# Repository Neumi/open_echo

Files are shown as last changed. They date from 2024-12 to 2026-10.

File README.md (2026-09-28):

<div align="center">
  Open Echo Cover
</div>

## Universal Open-Source SONAR Controller and Development Stack

An ongoing open-source hardware and software project for building sonar systems for testing, boating, bathymetry, and research.

[Discord](https://discord.com/invite/rerCyqAcrw) | [Getting Started Guide](TUSS4470_shield_002/README.md) | [Hardware Files](TUSS4470_shield_002/TUSS4470_shield_hardware/TUSS4470_shield)

## Overview

Open Echo makes SONAR technology accessible for developers, researchers, and hobbyists. It supports a wide variety of commercial and DIY ultrasonic transducers in both water and air, covering frequencies from 40 kHz up to 1000 kHz.

Use cases range from reverse-engineering car parking sensors and reading depth data on a yacht, to operating a Lowrance Tripleshot side-scan transducer or streaming data to a Pixhawk on a custom boat.

### Key Features

* **Universal Transducer Support:** Works with commercial and DIY transducers in water and air.
* **Flexible Firmware:** Run the [RAW Data Firmware](TUSS4470_shield_002/getting_started_TUSS4470_firmware.md) to process echoes yourself, or the [NMEA Output Firmware](TUSS4470_shield_002/arduino/NMEA_DBT_OUT/NMEA_DBT_OUT.ino) for NMEA0183 DBT compatibility (sends depth data directly to PCs, Pixhawk, or marine controllers).
* **Python Interface:** The [desktop software](TUSS4470_shield_002/getting_started_interface.md) provides live raw data visualization and TCP data streaming.
* **Tested Range:** Confirmed depth tracking of >50 m in water.
* **Network Ready:** Includes a PicoW implementation (software only, the shield itself is Arduino UNO R3 compatible) that transfers RAW data over UDP directly to the Python interface.

## Hardware & Getting Started

The primary development platform is the [TUSS4470 Arduino Shield](TUSS4470_shield_002/). It stacks directly on top of an Arduino Uno to drive the TUSS4470 ultrasonic driver.

**Upcoming Board:** A new development version is in the works and will hopefully be released in the coming weeks. It features an on-board boost converter and slightly improved signal routing.

* **Powering (Current Board):** Provide driver voltage via Arduino VIN or the external XT30 connector. You can also currently use an MT3608 boost converter to step up USB power to your required drive voltage (requires manual soldering until the new board is released).
* **Capabilities:** Drives transducers from 40–1000 kHz, filters signals, and sends raw echo data to the backend. It captures 1800 samples at 13.2 µs/sample (roughly an 18m range in water at 8-bit resolution). You can manually add delays in the code to extend the detection range for further distances.

### Getting the Hardware

1. **Elecrow (Pre-Built):** Buy a fully assembled and tested board here: [Elecrow Open Echo TUSS4470](https://www.elecrow.com/open-echo-tuss4470-development-shield.html)
2. **Build Your Own:** Order the [Hardware Files](TUSS4470_shield_002/TUSS4470_shield_hardware/TUSS4470_shield) from your preferred PCB manufacturer (JLCPCB recommended).
3. **Directly from me (Germany/EU):** If Elecrow is out of stock or you want to reduce shipping costs within Germany, email me at: `openechoes@gmail.com`.

> **Note:** All profits go directly toward supporting the project. Please understand that I can only provide support if you order the boards directly from me or Elecrow.

## Open Echo Interface Software

The [Python Interface Software](TUSS4470_shield_002/echo_interface.py) connects to boards running the RAW Data Firmware. It serves as a simple backend to view live echograms and output TCP depth data streams. (Configuration tweaking directly from the UI will be added later).

Live echogram in water (6x speed):  
Software running with live echo data

*(Static raw data waterfall chart available [here](documentation/images/echo_software_screenshot.jpg))*

## Test Results: Baltic Sea

Tested using a built-in 150 kHz SEAFARER transducer, powered at 15-20 V via an MT3608 boost converter from USB. Data capture in the plots begins at the bottom.

<table>
  <tr>
    <td align="center">
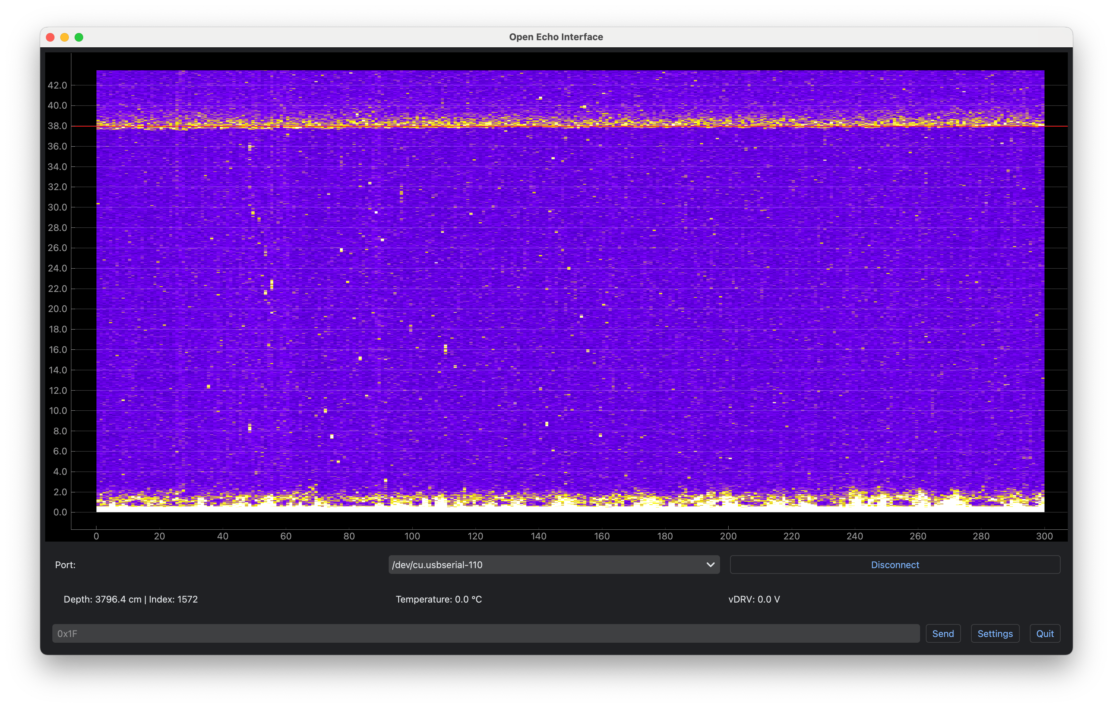
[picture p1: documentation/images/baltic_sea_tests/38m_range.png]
38m Range
      <br/>
      <sub><b>38 m range test</b></sub>
    </td>
    <td align="center">
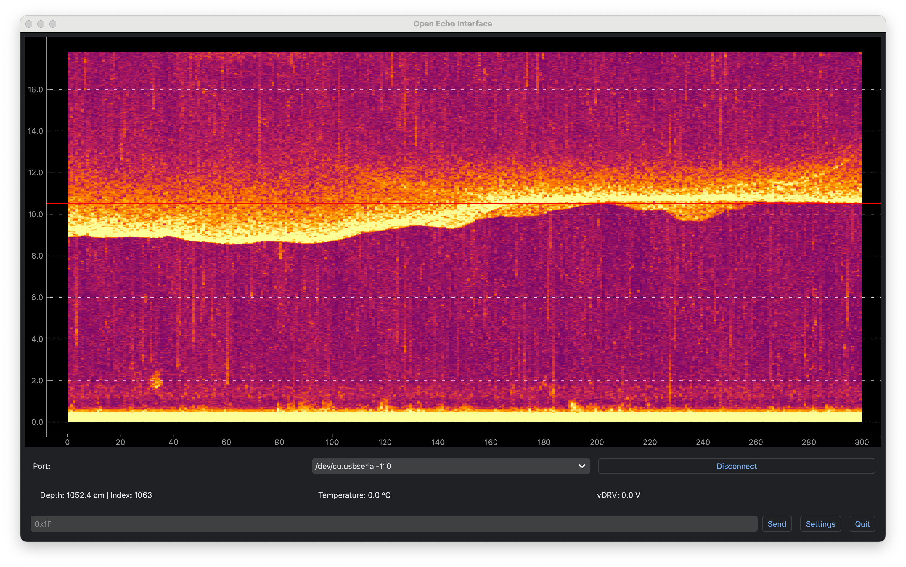
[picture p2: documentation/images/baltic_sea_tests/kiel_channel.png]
Kiel Channel
      <br/>
      <sub><b>Kiel Channel sand and mud</b></sub>
    </td>
    <td align="center">
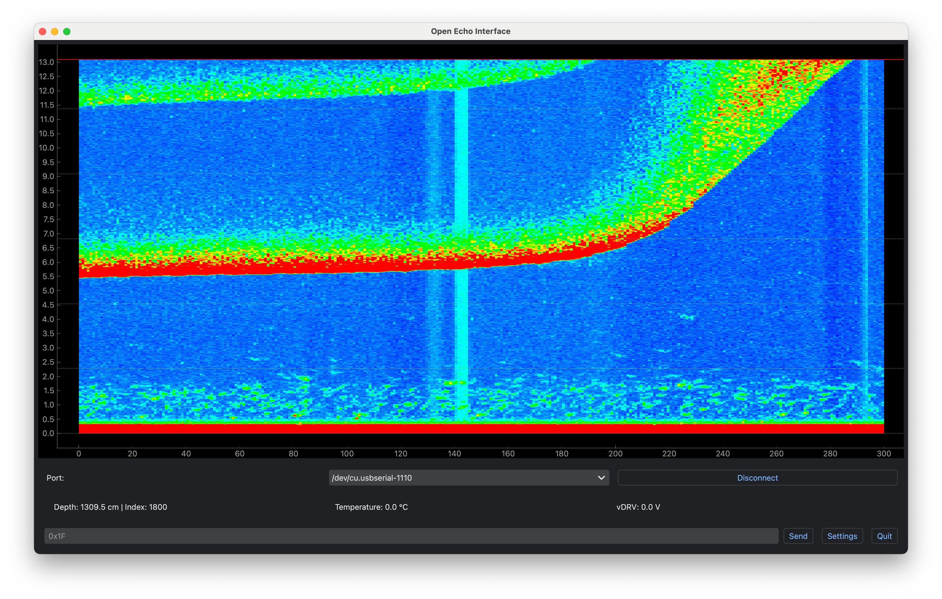
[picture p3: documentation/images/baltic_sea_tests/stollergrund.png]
Stollergrund
      <br/>
      <sub><b>Slope near Stollergrund</b></sub>
    </td>
  </tr>
  <tr>
    <td align="center">
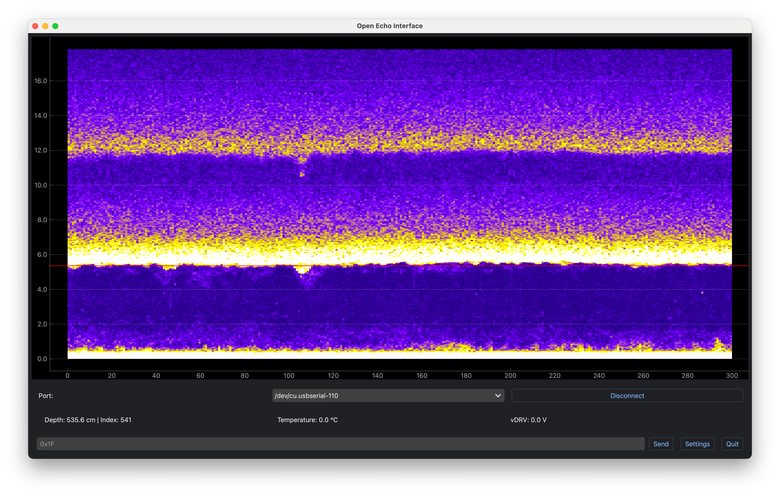
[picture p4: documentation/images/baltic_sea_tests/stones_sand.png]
Stones and Sand
      <br/>
      <sub><b>Stones and sandy seabed</b></sub>
    </td>
    <td align="center">
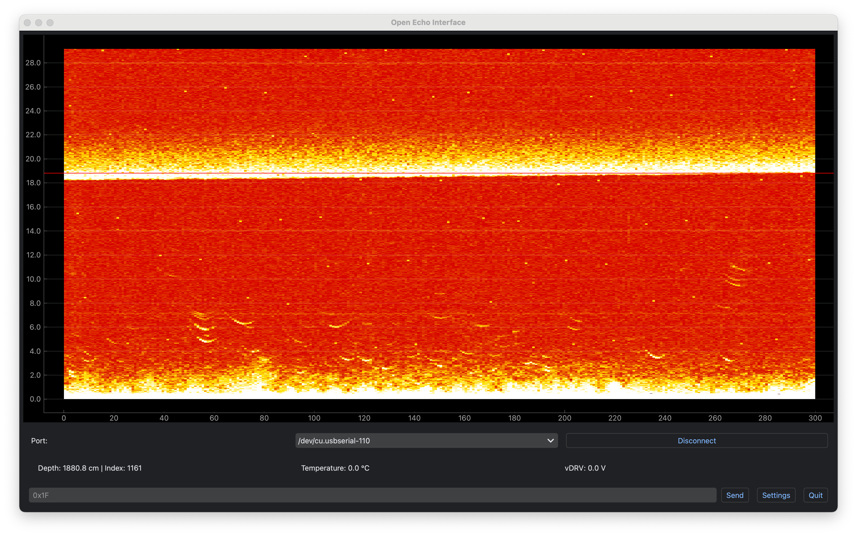
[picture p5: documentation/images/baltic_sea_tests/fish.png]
Fish
      <br/>
      <sub><b>Fish detection</b></sub>
    </td>
    <td align="center">
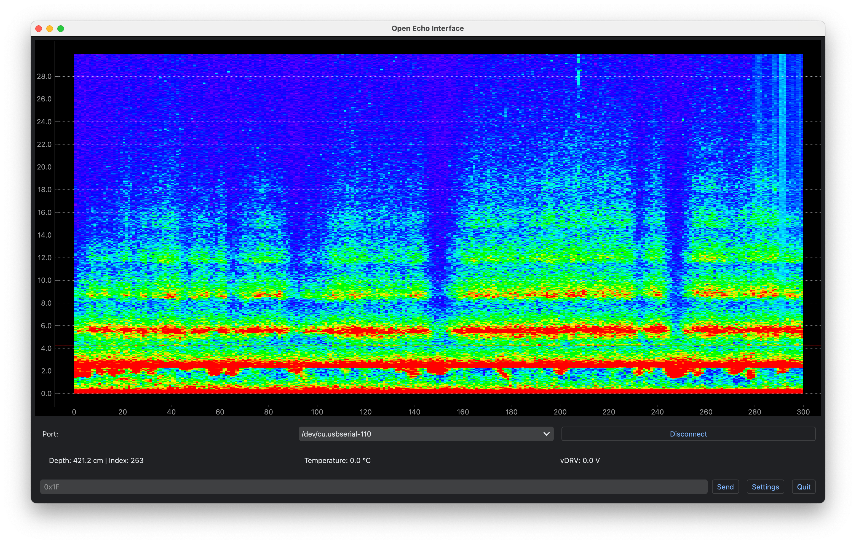
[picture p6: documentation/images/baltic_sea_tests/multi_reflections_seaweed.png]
Multiple Reflections
      <br/>
      <sub><b>Multiple reflections and seaweed</b></sub>
    </td>
  </tr>
</table>

## Transducers

Open Echo has been tested with multiple transducers. Here is a curated list of tested hardware:

| Transducer Name | Rating | Description | Freq. | Range Air/Water | Price | Link |
| --- | --- | --- | --- | --- | --- | --- |
| NASA / Seafarer 150kHz | ⭐⭐⭐ | NASA in-hull boat transducer for echo sounding / fish-finding | 150kHz | >2m / >50m | 50-100€ | [Link](https://www.nasamarine.com/product/depth-transducer-with-7-metre-cable/7) |
| Raymarine CPT-S | ⭐⭐⭐ | High-quality in-hull transducer with two frequencies | 50/200kHz | 2m / >50m | 200€ | [Link](https://www.raymarine.com/de-de/unsere-produkte/fischfinder-und-sonarmodule/fischfindergeber/cpt-s-durchbruchgeber) |
| Lowrance Tripleshot | ⭐⭐⭐ | Sidescan transducer (three FANS + temp + down-scan) | 200/455/600kHz | 0m / >20m | 200€ | [Link](https://www.echolotzentrum.de/shop/lowrance-tripleshot-heckgeber/) |
| Cheap Bathymetry | ⭐⭐⭐ | Good range and price/performance (can be hard to order) | 200kHz | 2m / >30m | 25€ | [Link](https://www.alibaba.com/product-detail/Range-customization-lakes-river-surveys-no_1600829423846.html) |
| Car Parking Sensor | ⭐⭐ | Great for air, works in water (not recommended for marine) | 40kHz | >7m / >30m | 5€ | [Link](https://de.aliexpress.com/item/1005006546490802.html) |
| Water Flow Sensor | ⭐⭐ | Cheap (Air & Water). Very narrow beam in water (~5°)! | 1000kHz | 0.25m / >10m | 16€ (5pcs) | [Link](https://de.aliexpress.com/item/32818381566.html) |
| Sinter Glass (Air Only) | ⭐ | Sinter glass matching layer, strictly for air use | 200kHz | 0.8m / (>8m) | 10€ | [Link](https://de.aliexpress.com/item/1005006007865920.html) |
| Encapsulated Transducers | ⭐ | Good for short-range testing at higher frequencies | 200-400kHz | ?m / ?m | 9-18€ | [Link](https://de.aliexpress.com/item/4000389134890.html) |
| Small PZT Only | ⭐ | Bare component, only for raw experimentation | 200kHz | 0.2m / ?m | 10€ | [Link](https://de.aliexpress.com/item/1005007032482539.html) |

> **Note:** The range values were measured using the TUSS4470 shield on an Arduino Uno with an MT3608 boost converter set to 20V for `vDRV`. Consider them approximate.

> **Tip:** Lower frequencies propagate farther, while higher frequencies produce narrower beams and more detailed echoes. For bathymetry, the first four options work best. Most commercial marine-grade transducers are suitable as long as they operate between 40 and 1000 kHz.

## Media & Resources

### Videos

Latest Project Update (https://www.youtube.com/watch?v=XF7rNGt6UYA)

https://www.youtube.com/watch?v=R3_NO2F7PsI  
https://www.youtube.com/watch?v=msbLVsY8xhQ  
https://www.youtube.com/watch?v=eJ8jVEQSx_Y  
https://www.youtube.com/watch?v=Bxh3rWd5RZk  
https://www.youtube.com/watch?v=UDYWQIizN7A  

### Links

* [Rapp Instruments: Side-Scan Sonar Info](https://www.rapp-instruments.de/RemoteSensing/Roves/sidescan/sidescan.htm)
* [Related Sonar Explanation Video](https://www.youtube.com/watch?v=ZtUkt8Q4EJE)

## Acknowledgments & Support

A big thanks to **[www.kogger.tech](http://www.kogger.tech)** for their continued support!

Thanks to our contributors:
* Check out the [Cheap Yellow Display Implementation](https://github.com/matztam/open_echo_cyd_display) by @matztam.
* Thanks to [@JohnCHarrington](https://github.com/JohnCHarrington/open_echo) for the firmware and software contributions.

### Star History
Star History Chart (https://www.star-history.com/#Neumi/open_echo&type=date&legend=top-left)

## Citation

If you use `open_echo` in your work or research, please cite the project:

* **ORCID:**  [0009-0003-9829-8959](https://orcid.org/0009-0003-9829-8959)

**BibTeX:**

```bibtex
@misc{open_echo,
  author       = {Jan Neumann},
  title        = {open\_echo},
  year         = {2026},
  publisher    = {GitHub},
  journal      = {GitHub Repository},
  howpublished = {\url{[https://github.com/Neumi/open_echo](https://github.com/Neumi/open_echo)}},
  note         = {ORCID: [https://orcid.org/0009-0003-9829-8959](https://orcid.org/0009-0003-9829-8959)}
}

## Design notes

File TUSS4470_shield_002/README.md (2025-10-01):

# Open Echo TUSS4470 Shield Getting Started Guide

The TUSS4470 is an ultrasonic driver and receiver IC designed for seamless interaction with ultrasonic transducers. The TUSS4470 Arduino Shield is a development board that enables quick evaluation of the TUSS4470's features using the Arduino UNO platform.

### Overview
This repository provides a quick-start guide and example Arduino sketches for experimenting with Time-of-Flight (ToF) applications using the TUSS4470. The shield is ideal for development, testing, and prototyping, but is not intended as a finished consumer product.

### Getting Started
Connect the shield to an Arduino UNO.

Upload one of the provided example sketches to explore different features of the TUSS4470.

Use the Python software to see the echoes.

### Ordering
The shield can be easily ordered via [JLCPCB](https://jlcpcb.com/?from=Neumi) or other PCB fabrication services.

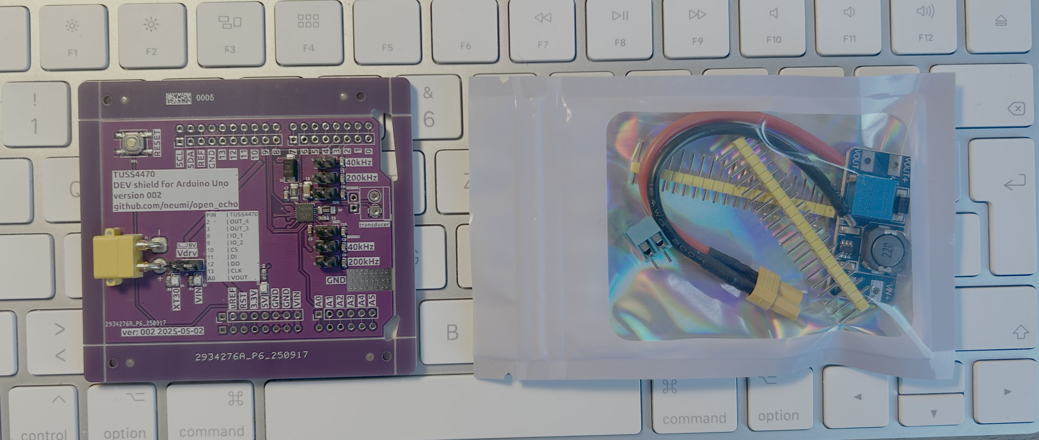
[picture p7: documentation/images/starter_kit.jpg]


> [!Note]
> I just got a few new boards, I sell as starter kits. Feel free to DM me on [Discord](https://discord.com/invite/rerCyqAcrw) if you're interested. Or send an email to: openechoes@gmail.com One assmebled board is 50€ + shipping. (10/2025)

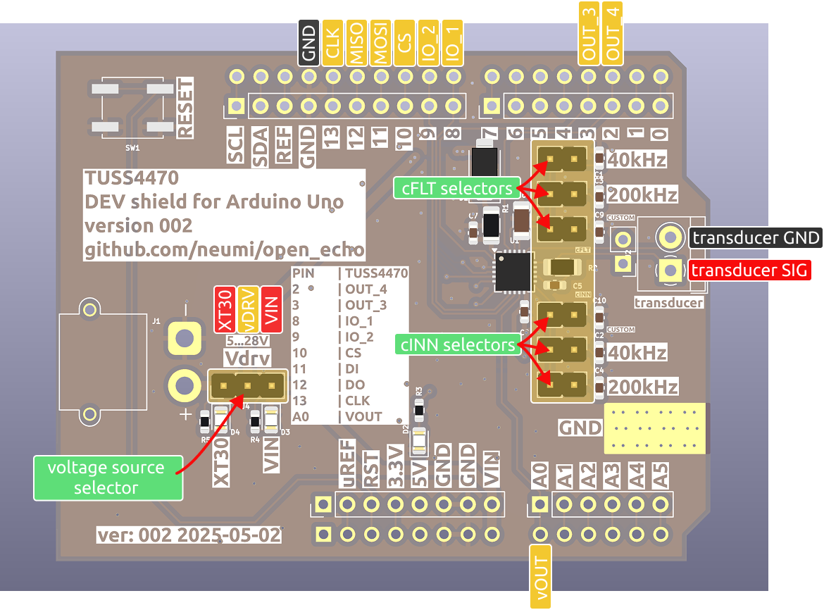
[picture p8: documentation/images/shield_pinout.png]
PCB overview TUSS4470


## Electrical Connections
The TUSS4470 Shield is designed specifically for use with the Arduino UNO. It is not software- or pin-compatible with other Arduino boards at this time.

### Pin Connections
The shield interfaces with the Arduino UNO the following:
- SPI interface
- Four digital GPIOs
- Analog pin A0

### cINN and cFLT Filtering Capacitor Selection for Transducer Frequency
To support different ultrasonic transducers and their respective drive frequencies, the board provides preset capacitor options for <b/>40, 150, 200 (and 600) kHz</b>.

> [!Important]
> Use the onboard jumpers to select the appropriate cINN and cFLT values.

### Custom Capacitor Configuration
If you need to drive transducers at frequencies other than the provided presets and combinations (40 kHz, 150 kHz, 200 (and 600) kHz), you can customize the capacitor values:
- Desolder the default "CUSTOM" capacitors. (for cINN and cFLT)
- Solder your own calculated capacitor values onto the "CUSTOM" pads.

> [!TIP]
> Capacitors can be combined in parallel to achieve intermediate values.
> For example, to support 150 kHz, both the 200 kHz and CUSTOM capacitors are used in parallel to produce the required total capacitance.
> On board version 002, "Custom" is pre-selected to match the right capacitances <b/>together</b> with the 200kHz capacitors for 150kHz. 

Below is the electrical connection layout for the cINN and cFLT capacitors and jumpers:
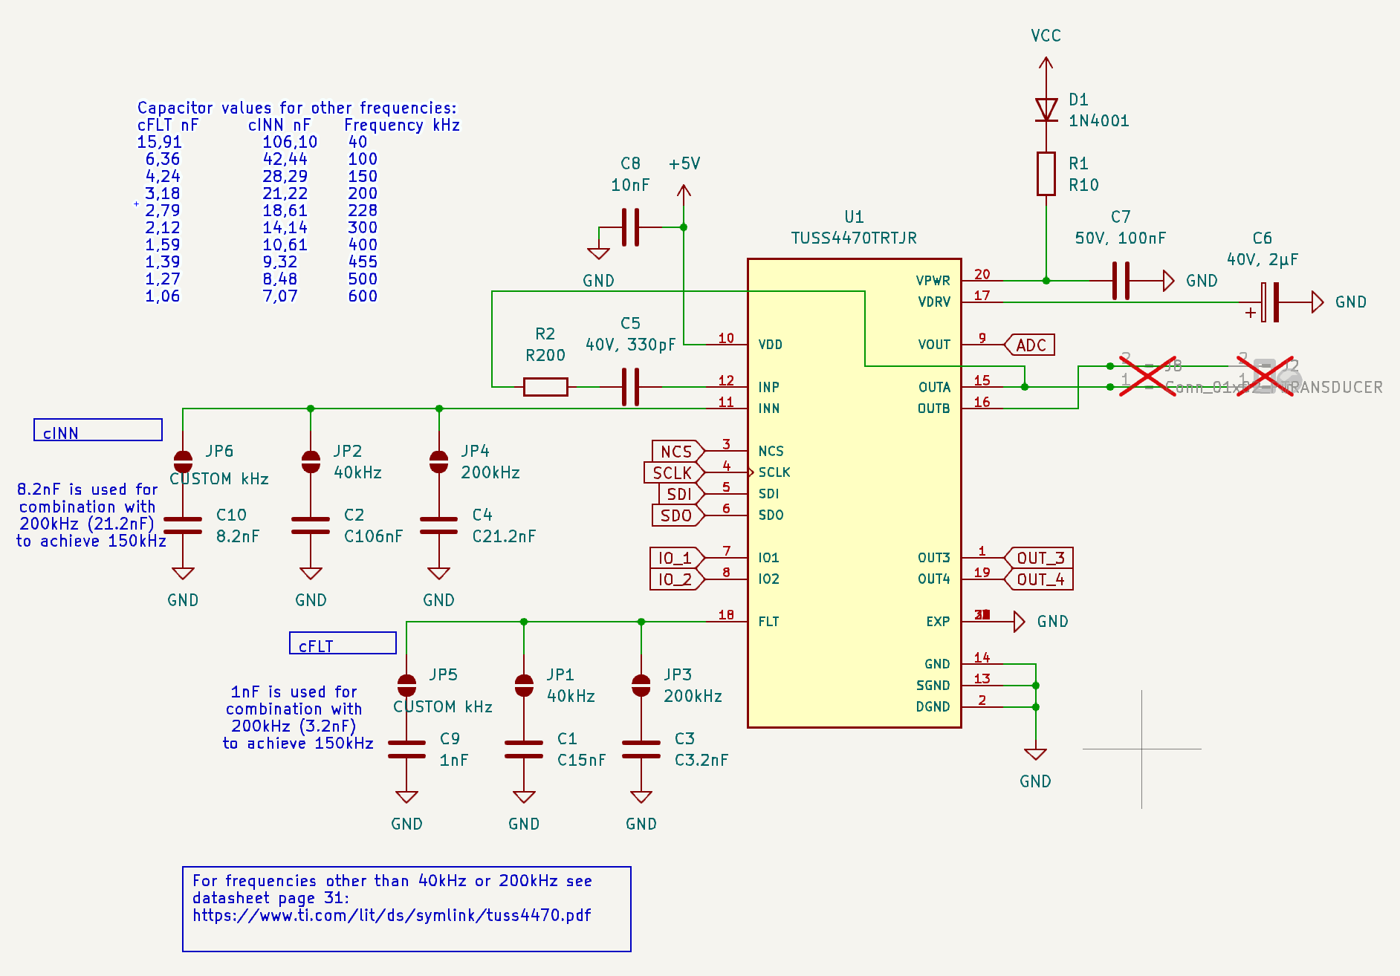
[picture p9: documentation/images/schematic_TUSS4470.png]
TUSS4470 schematic


### Power Supply Options
The board supports two power input options:
- VIN (Arduino VIN pin):
Use this when the transducer operates at 12V max, as the Arduino cannot tolerate higher voltages.

- XT30 Connector:
Use this if you require higher voltage (up to 28V max) for more powerful transducers.

- MT3608 Boost Converter:
You can add an MT3608 boost converter to your board to generate a higher vDRV from the USB 5V supply. This solution is reliable and works well in many applications, such as powering marine transducers.
Simply take the MT3608 module (included in the starter kits), secure it to the shield with double-sided tape, and connect the three wires as shown:
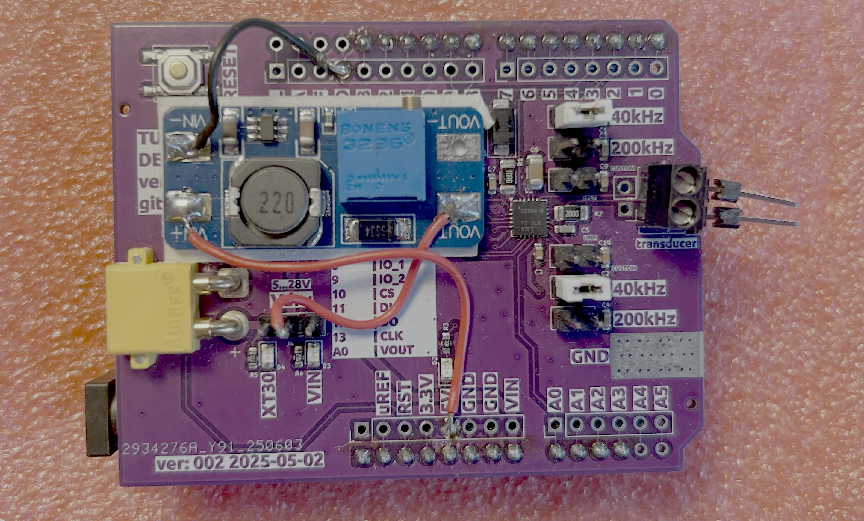
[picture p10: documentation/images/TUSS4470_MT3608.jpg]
TUSS4470 schematic


> [!Tip]
> To get started, use a 12V power supply. Many ultrasonic transducers operate reliably at this voltage.
> 
> Lower voltages may not adequately excite the transducer, resulting in weak or no echo signals.
> 
> The MT3608 should not be turned much further than 22V, as it becomes unstable.

> [!Warning]
> Do not exceed 28V input. Higher voltages can damage the board or components. Ensure proper polarity!

### Transducer Connection
Connect your PZT crystal or preassembled ultrasonic transducer to the "Transducer" header:

- Top pin: Ground (GND) / Shield
- Bottom pin: Signal

> [!Important]
> Proper polarity is crucial to minimize electrical noise and ensure optimal performance.
> For transducer connections exceeding 10 cm in length, use coaxial cable. Connect the cable shield to the transducer ground (GND).

The recommended setup is illustrated below:
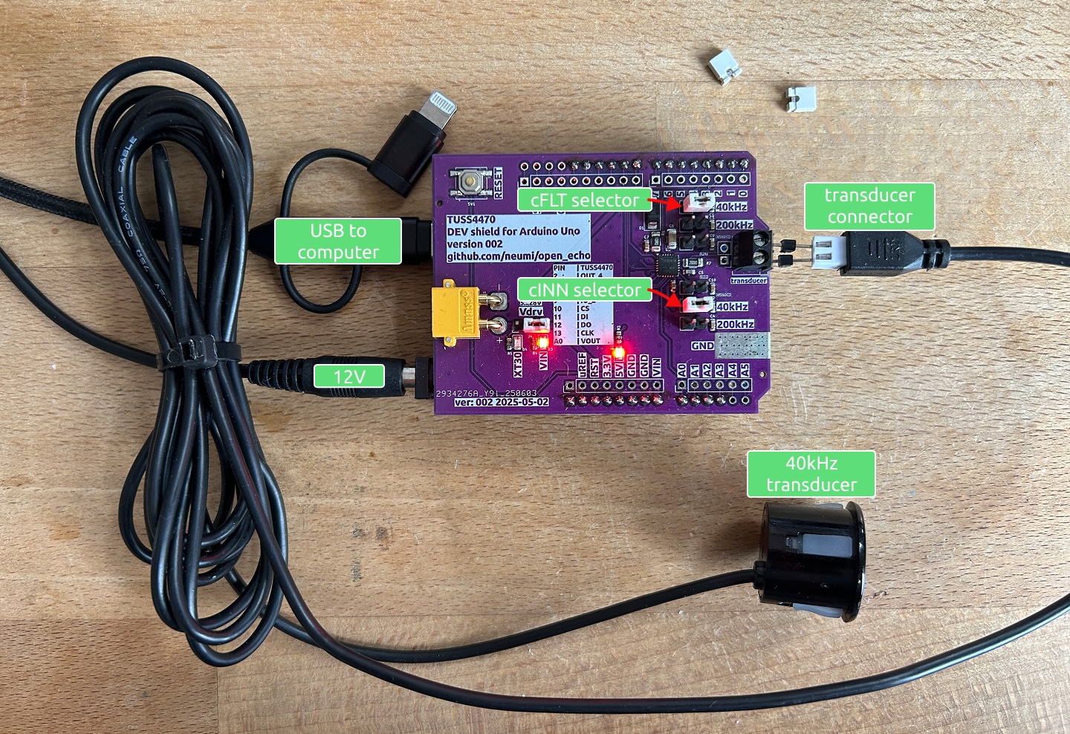
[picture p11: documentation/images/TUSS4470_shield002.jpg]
TUSS4470 Board ready to use


> [!Important]
> Always connect GND/Shield to the TOP pin on the transducer.
> Using the wrong pin increases powerline noise and significantly weakens the signal.

Below: Comparison of a transducer wired incorrectly (left half) vs. correctly (right half).
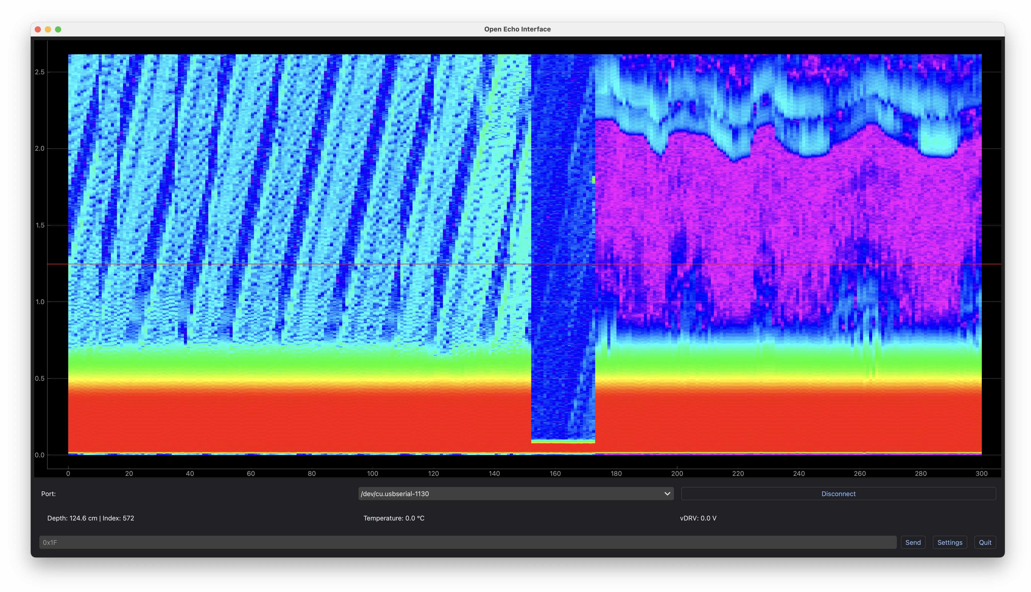
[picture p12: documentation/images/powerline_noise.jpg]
Powerline noise on transducer cable shield


<b/>Next Steps: Proceed to [Getting Started with Arduino TUSS4470 Firmware](getting_started_TUSS4470_firmware.md).</b>

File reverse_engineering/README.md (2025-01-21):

# open_echo

Reverse engineering of the LUCKY fishfinder to learn about ultrasonics projects from a real product.

Using a trigger and analog pin on an Arduino UNO we can read RAW echo data from the LUCKY fishfinder product.

As of today, there are at least three hardware versions of the LUCKY fishfinder. All of them seem to follow a similar concept, but the pinout is different!

LUCKY fishfinder pins:
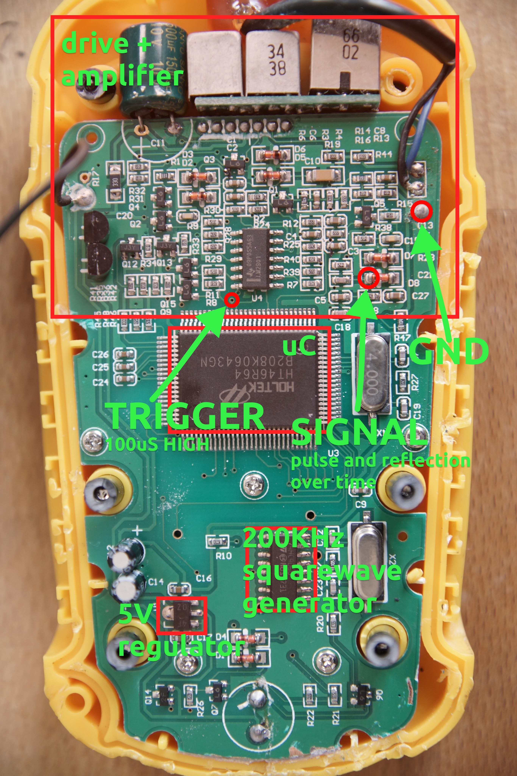
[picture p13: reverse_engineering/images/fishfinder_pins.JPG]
LUCKY fishfinder pin hack


Measured results using LUCKY fishfinder, FastLOGIC (Arduino) and Matplotlib + Python:
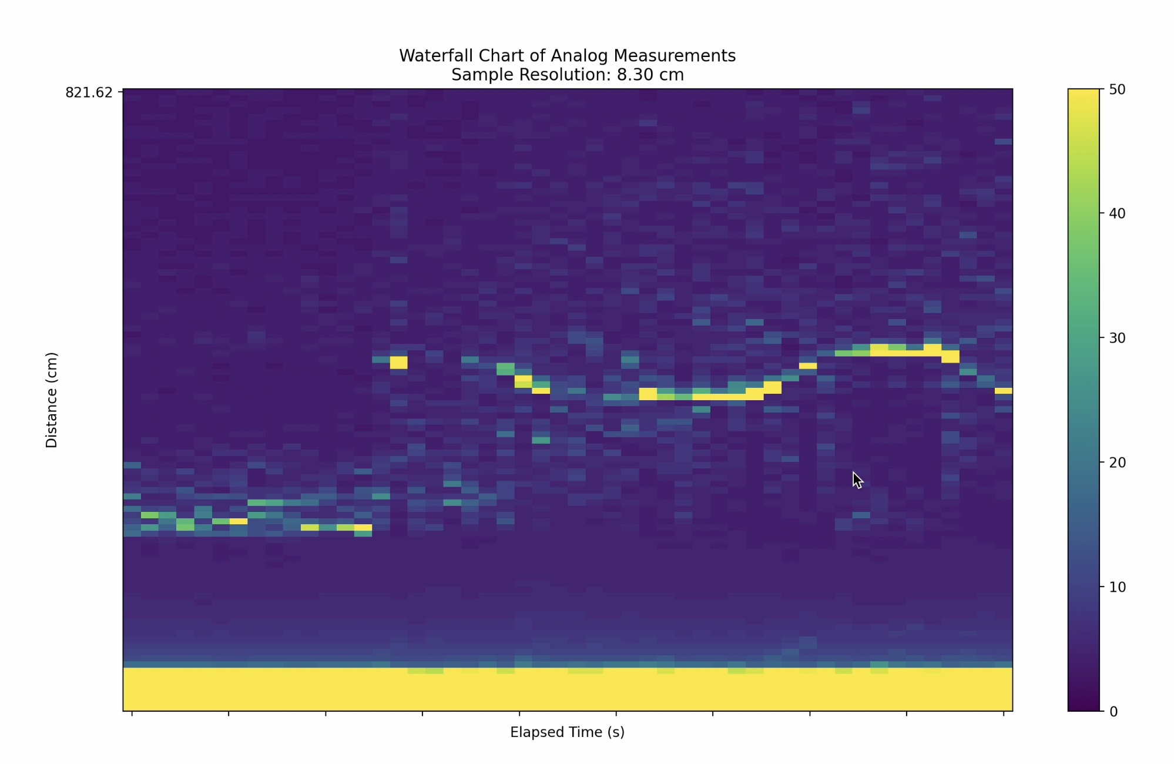
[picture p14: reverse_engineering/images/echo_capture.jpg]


The chart shows a measurement of reflection time (translated to cm using 1482m/s speed of sound in water) and the past 50 measurements. The LUCKY fish finder takes around 2.3 full measurements per second. The brigter the pixel, the stronger the return signal. The plot shows the sandy ground in the first 1/4 and the rest is the reflection of a metal ladder in the water (horizontal).

# More info in this video:
LINK TO VIDEO (https://www.youtube.com/watch?v=UDYWQIizN7A)

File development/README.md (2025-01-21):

# open_echo development
Less tested code, PCB designs and files. Not documented or ready for external use.

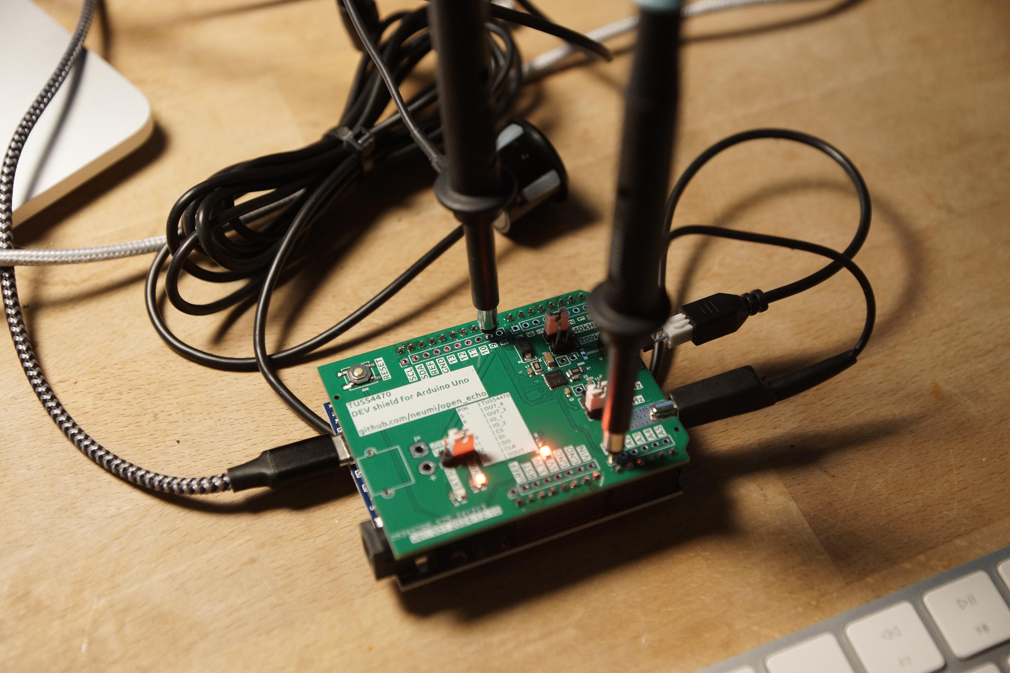
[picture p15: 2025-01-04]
TUSS4470_shield_002/TUSS4470_shield_hardware/images/perspective.jpg

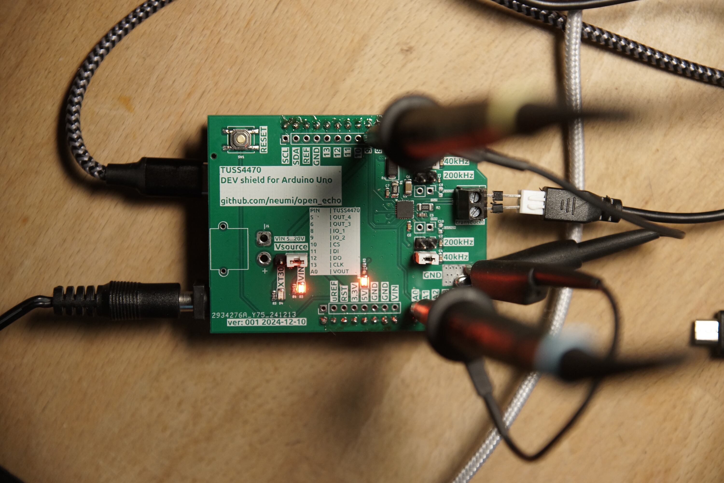
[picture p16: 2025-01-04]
TUSS4470_shield_002/TUSS4470_shield_hardware/images/top.jpg

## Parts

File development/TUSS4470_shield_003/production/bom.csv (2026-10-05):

Designator | Footprint | Quantity | Value | LCSC Part #
C1 | 0603 | 1 | 47pF 50V | C1671
C11 | 0603 | 1 | 1nF | C1588
C12 | 0603 | 1 | C15nF | C1596
C13 | 0603 | 1 | C3.2nF | C1613
C14 | 0603 | 1 | 8.2nF | C1322360
C15 | 0603 | 1 | C106nF | C14663
C16 | 0603 | 1 | C21.2nF | C21122
C17 | 0603 | 1 | 680pF | C1630
C18 | 0603 | 1 | 4.7nF | C53987
C2 | 1206 | 1 | 10uF 50V X5R | C13585
C3, C4 | 1206 | 2 | 4.7uF 50V X7R | C29823
C5 | 0603 | 1 | 40V, 330pF | C1664
C6 | 1206 | 1 | 40V, 2µF | C50254
C7, C9 | 0603 | 2 | 50V, 100nF | C14663
C8 | 0603 | 1 | 10nF | C57112
D1 | D_SMA | 1 | SMAJ36A | C19077550
D2 | 0805 | 1 | LED_PWR | C84256
D3, D5 | Nexperia_CFP3_SOD-123W | 2 | PMEG6010ELR | C179432
D4 | 0805 | 1 | LED_VPWR | C84256
J2 | PinHeader_1x03_P2.54mm_Vertical | 1 | TRANSDUCER
J4 | PinHeader_1x03_P2.54mm_Vertical | 1 | vINN SELECT | C49257
J9 | TerminalBlock_4Ucon_1x03_P3.50mm_Horizontal | 1 | TRANSDUCER
L1 | L_Taiyo-Yuden_NR-60xx | 1 | L | C16218
R1 | 1206 | 1 | R10 | C17903
R2 | 1206 | 1 | R200 | C25361
R3 | 0603 | 1 | R330 | C23138
R4 | 0603 | 1 | 374k | C25815
R5 | 0603 | 1 | R2.2k | C4190
R6 | 0805 | 1 | 0OHM | C17477
R7 | 0603 | 1 | 13.7k | C325658
R8 | 0603 | 1 | 75k | C23242
R9 | 0603 | 1 | 10k | C25804
SW1 | SW_Push_1P1T_NO_CK_KSC7xxJ | 1 | RST | C318884
U1 | QFN-20-1EP_4x4mm_P0.5mm_EP2.5x2.5mm_ThermalVias | 1 | TUSS4470TRTJR | C1855776
U2 | SOT-23-5 | 1 | LM2733XMF

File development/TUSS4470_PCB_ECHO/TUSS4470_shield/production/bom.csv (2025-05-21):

Designator | Footprint | Quantity | Value | LCSC Part #
C1, C21, C23, C8 | 0603 | 4 | 50V, 100nF | C14663
C10, C2 | 1206 | 2 | C10uF | C13585
C11, C13, C18, C28 | 0603 | 4 | C100nF | C14663
C12, C14 | 0603 | 2 | C10nF | C57112
C15, C16 | 0402 | 2 | C1nF | C1523
C17 | 0402 | 1 | C2.2nF | C1531
C19 | 0603 | 1 | 10nF | C57112
C20 | 0603 | 1 | 40V, 330pF | C1664
C22 | 0603 | 1 | C47nF | C1622
C24 | 0805 | 1 | C10uF | C440198
C25 | 1206 | 1 | 40V, 2µF | C50254
C29 | 1206 | 1 | C22uF | C12891
C3, C6, C7, C9 | 0402 | 4 | C100nF | C307331
C30 | 1210 | 1 | C22uF | C778721
C4, C5 | 0402 | 2 | C22pF | C1555
D1 | 0805 | 1 | LED_PC13 | C84256
D10, D5 | D_SMA | 2 | D_Schottky | C8678
D2, D3, D9 | D_SOD-323 | 3 | D_Schottky | C2128
D4 | 0805 | 1 | TX | C2297
D7 | 0805 | 1 | RX | C2297
INP1 | PinHeader_1x01_P2.54mm_Vertical | 1 | INP
J1 | TO-92L_Inline | 1 | DS18B20 | C157928
J2 | 200kHz_piezo | 1 | TRANSDUCER | C2997509
JP1 | PinHeader_1x02_P2.54mm_Vertical | 1 | termination_jumper
JP2 | SolderJumper-2_P1.3mm_Open_RoundedPad1.0x1.5mm | 1 | TVS
JP4 | SolderJumper-2_P1.3mm_Open_RoundedPad1.0x1.5mm | 1 | TRANSFORMER_BRIDGE
JP6 | SolderJumper-2_P1.3mm_Open_RoundedPad1.0x1.5mm | 1 | PHASE_DETECT
JP7 | SolderJumper-2_P1.3mm_Open_RoundedPad1.0x1.5mm | 1 | TRANSDUCER_GND
L1 | L_Bourns_SRN6045TA | 1 | L22uH | C780213
OUTA1 | PinHeader_1x01_P2.54mm_Vertical | 1 | OUTA
OUTB1 | PinHeader_1x01_P2.54mm_Vertical | 1 | OUTB
PIEZOA1 | PinHeader_1x01_P2.54mm_Vertical | 1 | TRANSDUCER_A
PIEZOB1 | PinHeader_1x01_P2.54mm_Vertical | 1 | TRANSDUCER_B
R1 | 0402 | 1 | R1M | C26083
R10, R14, R2 | 0603 | 3 | R1k | C21190
R11 | 1206 | 1 | R10 | C17903
R12 | 0603 | 1 | R4.7k | C23162
R13 | 1206 | 1 | R200 | C18002
R15 | 0402 | 1 | R100k | C25741
R16 | 0603 | 1 | R2.2k | C4190
R3, R4, R5, R6, R9 | 0603 | 5 | R10k | C25804
R7, R8 | 0603 | 2 | R330 | C23138
RV1 | Potentiometer_Bourns_3296W_Vertical | 1 | R_POT_100k
SW1 | SW_Push_1P1T_NO_CK_KSC7xxJ | 1 | RST | C318884
T1 | ultrasonic_transformer_THT | 1 | Transformer_1P_SS
TP1, TP3, TP5 | TestPoint_Pad_D2.0mm | 3 | GND
TP2 | PinHeader_1x01_P2.54mm_Vertical | 1 | BOOST
TP6 | TestPoint_Pad_D2.0mm | 1 | D-
TP7 | TestPoint_Pad_D2.0mm | 1 | D+
TP8 | TestPoint_Pad_D2.0mm | 1 | 5V
TP9 | PinHeader_1x01_P2.54mm_Vertical | 1 | VPWR
U1 | SOT-223-3_TabPin2 | 1 | AMS1117-3.3 | C6186
U2 | LQFP-48_7x7mm_P0.5mm | 1 | STM32F103C8Tx | C8734
U3 | QFN-28-1EP_5x5mm_P0.5mm_EP3.35x3.35mm | 1 | CP2102N-A01-GQFN28 | C6568
U4 | QFN-20-1EP_4x4mm_P0.5mm_EP2.5x2.5mm_ThermalVias | 1 | TUSS4470TRTJR | C1855776
U5 | SOT-23-6 | 1 | MT3608 | C84817
Y1 | Crystal_SMD_5032-2Pin_5.0x3.2mm | 1 | Crystal | C115962

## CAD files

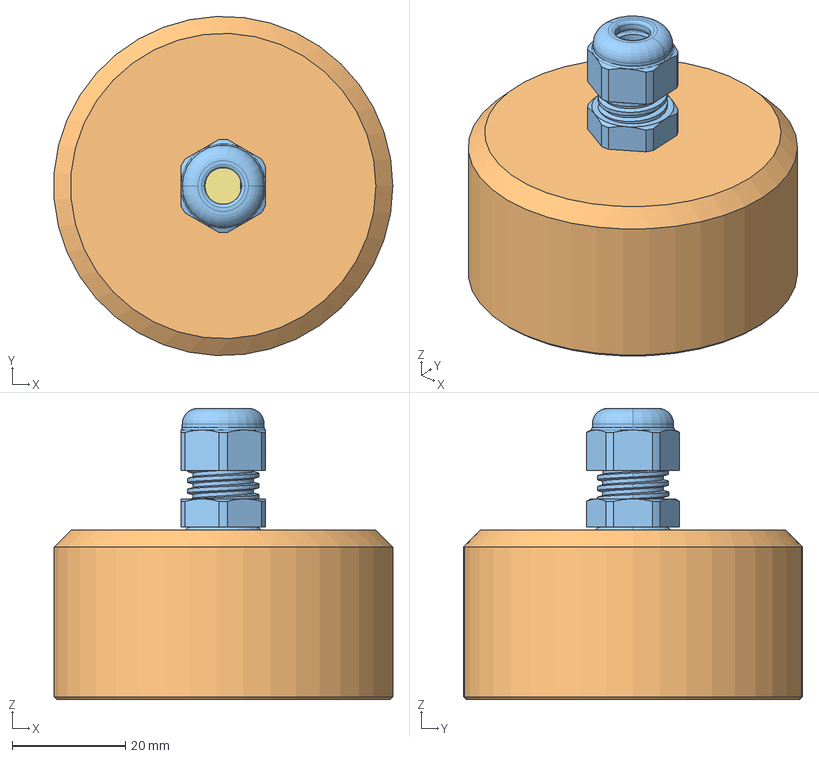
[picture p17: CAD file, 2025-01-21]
development/TUSS4470_PCB_ECHO/assembly.FCStd
59.9 x 60.0 x 51.5 mm
C_1206_3216Metric
R_1206_3216Metric
C_0402_1005Metric
R_0603_1608Metric
LED_0805_2012Metric
R_0603_1608Metric002
R_0402_1005Metric
C_0402_1005Metric002
QFN-20-1EP_4x4mm_Pitch0.5mm
D_SMA
R_0603_1608Metric004
C_0603_1608Metric
R_0603_1608Metric006
C_0402_1005Metric004
C_1206_3216Metric002
LED_0805_2012Metric002
LED_0805_2012Metric004
LQFP_48_7x7mm_P05mm
C_0603_1608Metric002
C_0603_1608Metric004
C_0402_1005Metric006
C_1206_3216Metric004
R_0603_1608Metric008
LED_0805_2012Metric006
C_1206_3216Metric006
C_0603_1608Metric006
SOT_223
R_1206_3216Metric002
LED_0805_2012Metric008
Crystal_SMD_5032-2Pin_5.0x3.2mm
C_0402_1005Metric008
C_0402_1005Metric010
C_0603_1608Metric008
R_0603_1608Metric010
R_0603_1608Metric012
R_0603_1608Metric014
C_1206_3216Metric008
C_0603_1608Metric010
QFN-28-1EP_5x5mm_Pitch0.5mm
_autosave-TUSS4470_shield_PCB
69915K47_Plastic Submersible Cord Grip

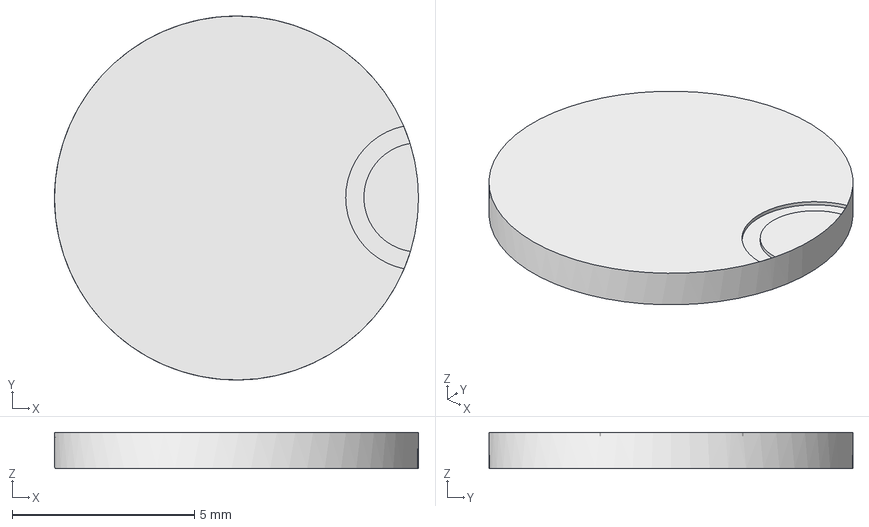
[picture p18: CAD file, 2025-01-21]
development/TUSS4470_PCB_ECHO/TUSS4470_shield/components/piezo_3d.step
10.00 x 10.00 x 1.00 mm

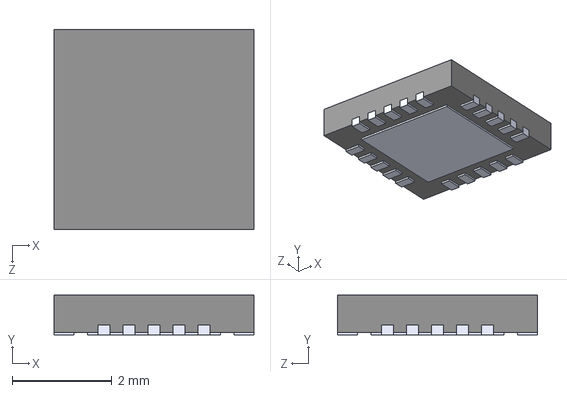
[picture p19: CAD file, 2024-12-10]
development/TUSS4470_shield_003/components/TUSS4470TRTJR.step
4.00 x 0.8 x 4.00 mm

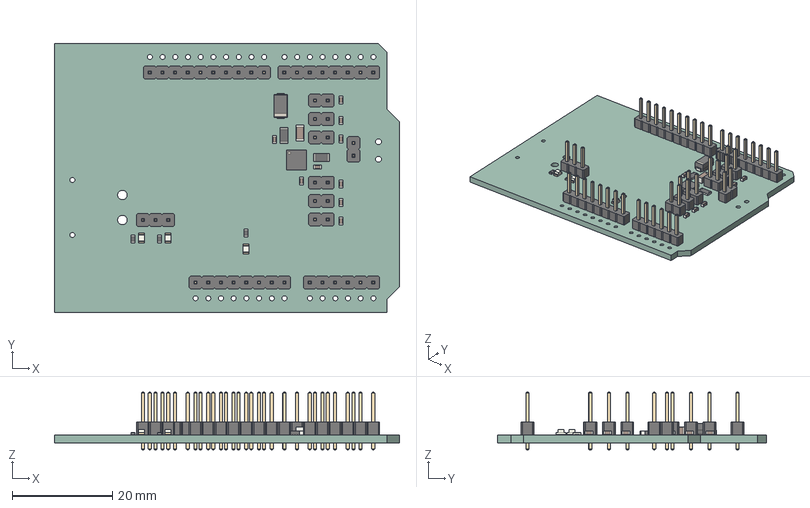
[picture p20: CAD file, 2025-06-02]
development/TUSS4470_shield_003/TUSS4470_shield.step
69.0 x 53.8 x 11.5 mm
R_1206_3216Metric x 2
LED_0805_2012Metric x 3
QFN-20-1EP_4x4mm_Pitch0.5mm
D_SMA
C_0603_1608Metric x 9
PinHeader_1x02_P254mm_Vertical x 7
PinHeader_1x06_P254mm_Vertical
R_0603_1608Metric x 3
C_1206_3216Metric
PinHeader_1x08_P254mm_Vertical x 2
PinHeader_1x10_P254mm_Vertical
PinHeader_1x03_P254mm_Vertical
TUSS4470_shield_PCB

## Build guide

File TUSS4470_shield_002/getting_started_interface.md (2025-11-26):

# Getting Started Open Echo Interface Software

The [***Open Echo Interface***](echo_interface.py) is a cross-platform Python application that interacts with the Arduino + TUSS4470 Shield. 
It displays ultrasonic echo data in real-time using a waterfall chart visualization. 
The application is intended primarily as a testing and development tool, but is stable enough for continuous use -tested for several days on a Raspberry Pi 4 without issues.

### Key Features
- Connects to Open Echo hardware over serial or UDP
- Displays real-time and historical data in a waterfall chart
- Auto-gain to adjust the waterfall chart colors
- Shows detected depth, and (if supported) temperature and drive voltage (`vDRV`)

> **Note**  
> This interface is primarily intended for development and testing. It's proven stable, but not yet a polished end-user application.

---

## Installation & Setup

### 1. Create and activate a virtual environment

```bash
cd open_echo/TUSS4470_shield_002
python3 -m venv venv 
source venv/bin/activate 
```

### 2. Install requirements
```bash
pip install -r requirements.txt 
```

### 3. Start Open Echo Interface Software
```bash
python echo_interface.py
```

Select the correct COM port, then click Connect or press c on your keyboard. Once connected, the Open Echo board will begin streaming data, which will appear on the right side of the interface.
The red horizontal line indicates the currently detected depth, based on the strongest first echo received after the ring-down delay.

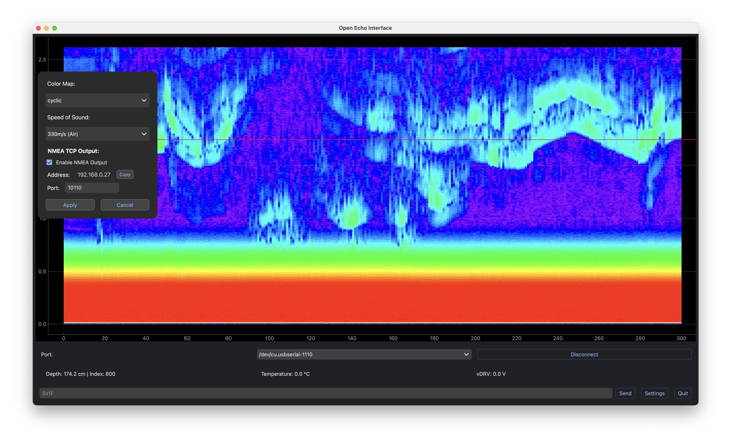
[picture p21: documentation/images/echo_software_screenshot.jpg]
Open Echo Interface Software


### 4. Change to your own needs

You can change different settings in the first lines of the [**Open Echo Interface**](echo_interface.py) code to customize it to your specific use cases.

### 📊 Parameter Settings

| Parameter | Description |
|---|---|
| `BAUD_RATE` | Must match the baud rate configured in the Arduino firmware. |
| `NUM_SAMPLES` | Must match the `NUM_SAMPLES` value used in the Arduino firmware. |
| `MAX_ROWS` | Sets the number of historical measurements displayed in the chart before it scrolls. |
| `Y_LABEL_DISTANCE`| Defines the vertical axis label spacing, in centimeters. |
| `SPEED_OF_SOUND`  | Used to convert sample timing into distance. Set to ~330 for air, ~1450 for water. |
| `SAMPLE_TIME` | Sampling interval in microseconds. For the Arduino UNO with [TUSS4470_arduino.ino](arduino/TUSS4470_arduino/TUSS4470_arduino.ino), this must be set to **13.2 µs**. |

--- 
Want to stay updated, have questions or want to participate? Join my [Discord](https://discord.com/invite/rerCyqAcrw)!

Or write an issue. Thanks!

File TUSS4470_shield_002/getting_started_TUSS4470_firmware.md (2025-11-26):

# Getting Started with Arduino TUSS4470 Firmware

This repository provides two software components to support the TUSS4470 Arduino Shield:
- [Arduino Firmware](arduino/TUSS4470_arduino/TUSS4470_arduino.ino) - Runs on an Arduino UNO board with the TUSS4470 shield and handles signal generation, echo capture, and communication.
- [Open Echo Interface](echo_interface.py) - A desktop application that communicates with the Arduino, displays echo data as a real-time waterfall chart, and will soon allow runtime configuration of the system.

## Arduino Firmware
The Arduino firmware initializes the TUSS4470 device and manages the ultrasonic signal transmission and echo reception cycle. It sends digitized echo data over the serial interface to a host computer for analysis.

<b/>Key Features</b>
- SPI communication with TUSS4470 chip
- Configurable drive frequency
- Adjustable sampling size (defines detection range)
- Basic bandpass filtering options
- Threshold detection for bottom line detection
- Binary data transfer to Python software

> [!NOTE]
> The firmware is designed to be easily modified. Users are encouraged to experiment with parameters to suit their application needs.

## Uploading the Firmware
1. Open the Arduino IDE.
2. Select your Arduino UNO board and the correct COM port.
3. Set the configuration as described below.
4. Load the firmware sketch [TUSS4470_arduino.ino](arduino/TUSS4470_arduino/TUSS4470_arduino.ino).
5. Upload the sketch to the Arduino UNO.

## ⚙️ Configuration Parameters
Below are the key parameters used to control the ultrasonic transducer behavior, echo processing, filtering and outputs. `NUM_SAMPLES` must be kept in sync with the [Open Echo Interface](echo_interface.py). Due to RAM limitations on the Arduino UNO R3, it can't exceed ~1800 samples. The Arduino UNO R4 can reach ~12000 samples.

### 📊 Settings

| Parameter | Description |
|---|---|
| `NUM_SAMPLES` | Total number of ADC samples per measurement cycle. Must match the sample size used in visualization. Each sample is approximately **13.2 µs** long. |
| `BLINDZONE_SAMPLE_END` | Number of initial samples to ignore after sending the ultrasonic pulse. Avoids transducer ringdown echoes. |
| `THRESHOLD_VALUE` | Echo amplitude threshold for detecting the bottom. First echo stronger than this (after blind zone) is used. |

```cpp
#define NUM_SAMPLES 1800         // One frame of data at full sampling speed (~24 ms) -> in water ~18m -> in air ~4m
#define BLINDZONE_SAMPLE_END 200 // Ignore first 200 samples during early transducer ringdown
#define THRESHOLD_VALUE 0x19     // Echo strength threshold for bottom or obstacle detection
```

### 📡 Transducer Drive Frequency

The ultrasonic burst frequency is set by configuring **DRIVE_FREQUENCY**.
Enter the resonant frequency in Hz of your transducer. The TUSS4470 supports drive frequencies between 40 and 1000 kHz.

**Example Configuration:**
For **40 kHz**:  
```cpp
#define DRIVE_FREQUENCY 40000
```

#### 🔧 Alternative Frequencies

| Frequency | Notes |
|---|---|
| 40 kHz | Car parking sensor |
| 50 kHz | Raymarine CPT-S secondary frequency |
| 100 kHz | Chrhartz DIY transducer |
| 151 kHz | Muebau transducer |
| 200 kHz | Raymarine CPT-S |
| 216 kHz | Mini transducer |
| 230 kHz | 18mm transducer from AliExpress |
| 455 kHz | Lowrance Hook 3TS sidescan |
| 1000 kHz  | Water flow sensor transducer |

---

### 🎛️ Band-Pass Filter (TUSS4470)

To reduce noise and isolate the echo signals, a band-pass filter is configured on the **TUSS4470** IC. This should closely match the transducer’s drive frequency and the cFLT and cINN values on the board, see [Getting Started Guide](README.md#custom-capacitor-configuration).

**Example Configuration:**

```cpp
#define FILTER_FREQUENCY_REGISTER 0x00 // 40 kHz
```

#### 🧪 Other Filter Register Options

| Filter Register | Frequency | Notes |
|---|---|---|
| `0x00` | 40 kHz | Car parking sensor |
| `0x09` | 68 kHz | Secondary frequency [Raymarine CPT-S](https://www.raymarine.com/de-de/unsere-produkte/fischfinder-und-sonarmodule/fischfindergeber/cpt-s-durchbruchgeber)  |
| `0x10` | 100 kHz | Chrhartz transducer |
| `0x18` | 151 kHz | Muebau transducer |
| `0x1E` | 200 kHz | [Raymarine CPT-S](https://www.raymarine.com/de-de/unsere-produkte/fischfinder-und-sonarmodule/fischfindergeber/cpt-s-durchbruchgeber), [AliExpress 18mm](https://de.aliexpress.com/item/1005006007865920.html), [Alibaba](https://www.alibaba.com/product-detail/Range-customization-lakes-river-surveys-no_1600829423846.html) |

> 📖 For full configuration details, see the [TUSS4470 Datasheet – Table 7.1](https://www.ti.com/lit/ds/symlink/tuss4470.pdf).

### UDP Outputs (Arduino R4 Wifi Only)

If using the Arduino R4 Wifi, there is the option to output echoes and/or NMEA via UDP. Echo's output over UDP can be received by the python interface. NMEA depth output over UDP can be received by e.g. SignalK.

### Summary

To get started, upload the provided Arduino firmware [TUSS4470_arduino.ino](arduino/TUSS4470_arduino/TUSS4470_arduino.ino) to an Arduino UNO using the Arduino IDE. The firmware is preconfigured for a 40 kHz transducer (car parking sensor), which is ideal for first-time setup and testing. Once running, the Arduino continuously sends ultrasonic echo data over USB to the Open Echo Interface Python app for real-time visualization. You can customize parameters such as sample size, blind zone, detection threshold, drive frequency, and filter register to suit other transducers or application ranges. Just make sure NUM_SAMPLES matches in both the Arduino firmware and the Python interface. For most users, starting with the default 40 kHz setup provides the simplest and most reliable baseline.

<b/>Next Steps: Proceed to [Getting Started Open Echo Interface Software](getting_started_interface.md).</b>

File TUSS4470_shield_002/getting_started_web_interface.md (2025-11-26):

# Getting Started Open Echo Interface Software

The [***Open Echo Web Interface***](echo_interface.py) is a cross-platform Python application that interacts with the Arduino + TUSS4470 Shield. 
It displays ultrasonic echo data in real-time in the browser using a waterfall chart visualization. 
<!-- The application is intended primarily as a testing and development tool, but is stable enough for continuous use -tested for several days on a Raspberry Pi 4 without issues. -->

### Key Features
- Connects to Open Echo hardware over serial
- Displays real-time and historical data in a waterfall chart
<!-- - Auto-gain to adjust the waterfall chart colors -->
- Shows detected depth <!-- and (if supported) temperature and drive voltage (`vDRV`) -->
<!-- - Supports bidirectional communication for debugging and testing -->
- Shows depth at cursor on hover - useful for precise depths of non-ground echoes (fish!)

> **Note**  
> This interface is primarily intended for development and testing. It's proven stable, but not yet a polished end-user application.

---

## Installation & Setup

### 1. Create and activate a virtual environment

```bash
cd open_echo/TUSS4470_shield_002/web
python3 -m venv venv 
source venv/bin/activate 
```

### 2. Install requirements
```bash
pip install -r requirements.txt 
```

### 3. Start Open Echo Interface Software
Run the following command to start the web server. 
```bash
python3 -m uvicorn --host=0.0.0.0 --port=8000 app:app
```
Then go to http://localhost:8000. The first connection will be redirected to /config to set up the connection, then you should see your echoes.

--- 
Want to stay updated, have questions or want to participate? Join my [Discord](https://discord.com/invite/rerCyqAcrw)!

Or write an issue. Thanks!

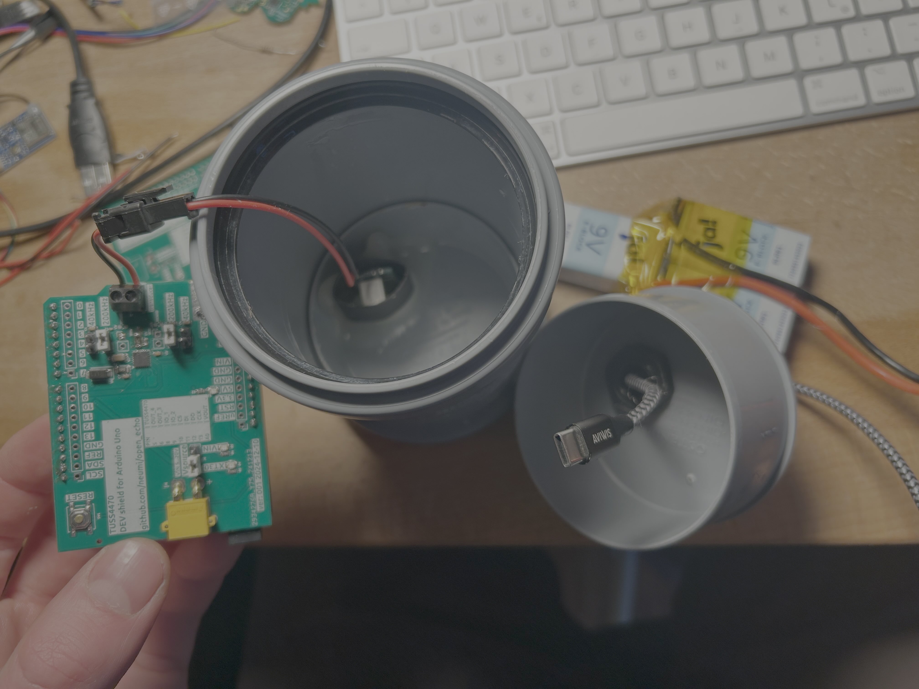
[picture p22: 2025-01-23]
documentation/images/transducer_assembly.JPG

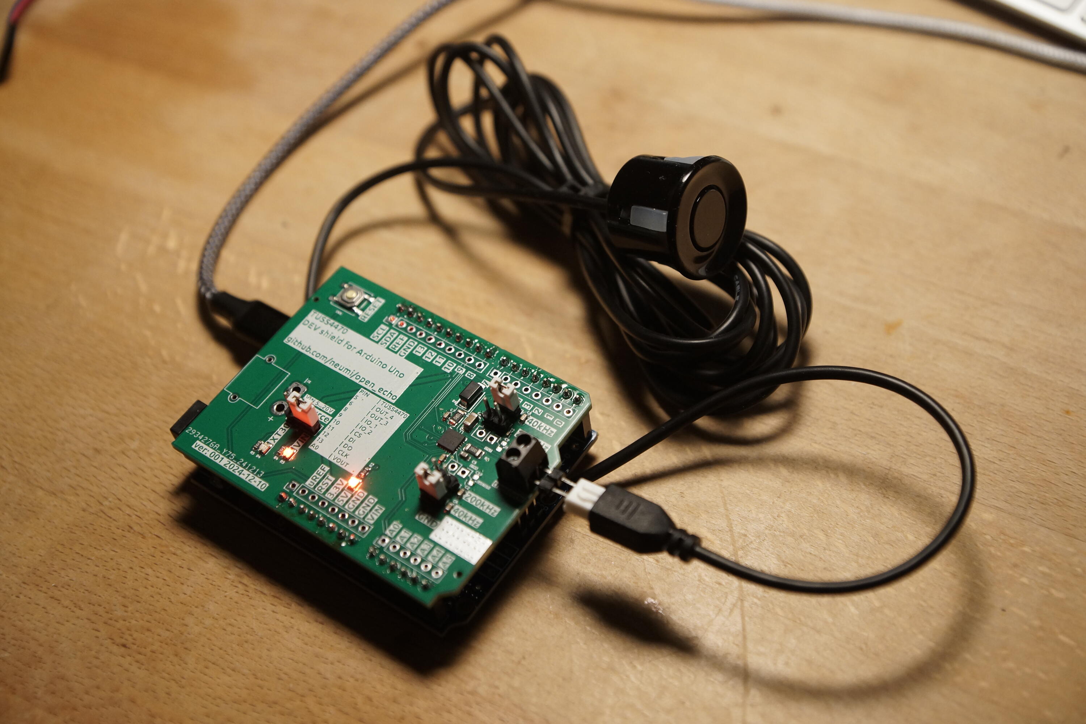
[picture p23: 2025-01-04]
TUSS4470_shield_002/TUSS4470_shield_hardware/images/assembly2.jpg

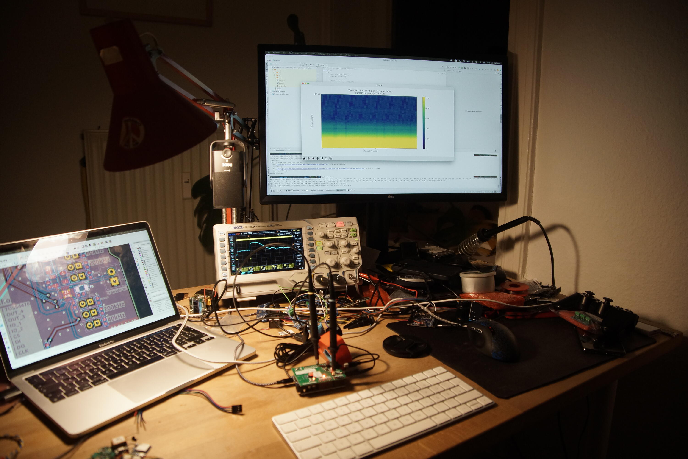
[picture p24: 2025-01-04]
TUSS4470_shield_002/TUSS4470_shield_hardware/images/whole_setup.jpg

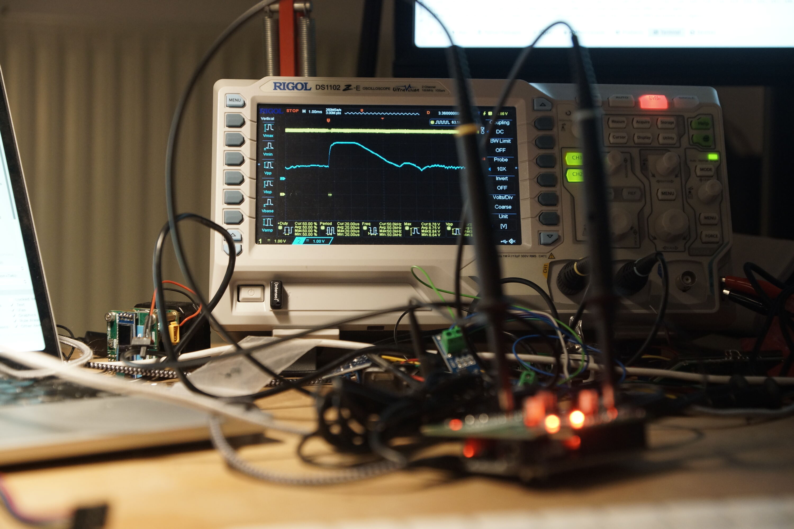
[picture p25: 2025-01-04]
TUSS4470_shield_002/TUSS4470_shield_hardware/images/setup.jpg

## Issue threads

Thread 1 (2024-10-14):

about project.

zurkes, 2024-10-14:
lucky fish finder is already a working product. what is the purpose of this project?

jkknibbe99, 2024-10-14:
> lucky fish finder is already a working product. what is the purpose of this project?

I could see it being useful to get the depth data on to another device such as a laptop. There, the data can be stored and plotted to create [depth maps](https://photos.bwca.com/m/MAD_ANGLER-190218-142152.JPG) or other similar charts.

Neumi, 2024-10-21:
Thanks @zurkes for the issue. The video in the readme should explain it.
But the goal is to build an open source echo sounder hardware and software that can be adapted to your use cases and also readable by common hardware like Arduino or similar.
The Lucky Fish Finder is a working product you can buy, but you normally can't read it using an Arduino or computer backend.
I needed a readable sonar hardware for this project: https://github.com/Neumi/3D_water_depth_logger
And because Arduino-readable hardware is either very expensive or hard to get, I thought it might be worthwhile building it myself.

Closed 2024-10-21.

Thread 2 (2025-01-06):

Thank you so much！

yq3w, 2025-01-06:
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
Hello, I bought a lucky fish finder, and after taking it apart, I found that the versions might be different, and the tentacles inside are also different. I am very happy to see that you have released a new pcb file. Maybe I can make a board, because I like lure fishing and want to build a fish finder. In the past few days, I have used a Raspberry Pi and an ultrasonic sensor that can only measure 1 meter distance. I have achieved some goals with reference to your py code, and I have a little understanding of ultrasonic sensors. I find it difficult to understand that only the time of the echo can be used to calculate the target distance to determine whether there is a fish. Does it also involve processing amplitude, etc., and are there many complex algorithms?

Neumi, 2025-01-06:
Hey there! Awesome progress!

Your LUCKY fishfinder definitely looks different. I noticed only two inductors this time, and it seems like there’s an extra WiFi or Bluetooth chip—possibly an ESPRESSIF ESP32 or ESP8266? It looks like the design might be easier to reverse engineer now, with fewer components overall. The frequency generator has shifted to the top, and the board seems more modern. I also spotted a programming header in the middle—rewriting the firmware on the microcontroller to get raw data could be an interesting route to explore. If you want to use the LUCKY fishfinder, you need an AD converter for the Raspberry PI, or an Arduino or similar.

Quick note—be careful when measuring directly on the transducer pins. Make sure to use the 10x mode on your probe since there’s quite a high voltage on those lines (around 120V p-p).

In my case, I didn’t use any DSP—just some amplification and thresholding because I displayed the RAW output. For a fishfinder, that is fine, too. If you need to see the exact depth as a number, you need some simple thresholding or DSP. The echo time correlates to distance, while the echo intensity varies depending on the material and surface it reflects from. Stronger echoes typically come from hard surfaces like rock or metal, while weaker echoes are from things like sand, mud, or fish.

This video explains a lot of these concepts quite well: https://www.youtube.com/watch?v=ZtUkt8Q4EJE.

THe PCB I built uses the TUSS4470. It handles everything the upper part of the LUCKY fishfinder PCB does. From signal generation, to receiving the echo, to filtering, amplification and even more. But you need an Arduino to use it. What ultrasonic sensor have you used on the Raspberry? I don't know any that supports higher frequencies than 40kHz. (for water you more likely need 100-200kHz and for higher resolution up to 800kHz)

Let me know how it goes!

yq3w, 2025-01-07:
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
Thank you very much for the quick response.

My Raspberry Pi ultrasonic transducer is used for learning purposes. One is responsible for transmitting and the other for receiving. The ultrasonic wave provides four pins for the Raspberry Pi to receive digital signals, allowing me to read the echo time and calculate the distance.

I found a signal that reflects the waveform and distance from the back contacts of the circuit board using an oscilloscope. It seems to be the RAW output you mentioned, but I haven't utilized it well yet. I need to convert the analog signal into a digital signal. I bought a PCF8591 analog-to-digital converter module, which can obtain some data, but I can't figure out how to use it; I don't know if the obtained data represents amplitude or something else.

I rewrote your code using ChatGPT, and the waterfall chart looks cute, but compared to your code, it lacks some colors to display objects and only shows the distance, possibly missing the signal strength.

Today, I will explore the lucky fish finder to see if I can discover something. I am not very skilled in electronics; I'm just a hobbyist.

A very important question I want to ask you is about creating an ultrasonic fish finder that can detect fish from the shore, like shining a flashlight on the water's surface to see if there are fish underneath. I want to check for fish in a fishing spot 20-30 meters away, and the precision of the fish's distance is not that important; what's important is whether there are fish and their size. I don't want to put the ultrasonic device into the water; that would be too troublesome. Will sound waves completely reflect back when they hit the water surface, or can they propagate from the air into the water? Please help me determine if my efforts in this direction have potential.

yq3w, 2025-01-08:
Thank you for the HC-SR04 information. I have gained a better understanding of how to send pulse signals. The Echo pin seems to only read 0 or 1. I did find a contact point, and the oscilloscope can clearly see the echo intensity. I also modified my Python program, and the echo intensity varies, showing different colors in the waterfall chart depending on the detected object. However, the analog-to-digital conversion seems to lack precision, and the obtained intensity data is not ideal.

I found some information stating that ultrasonic waves lose over 90% of their energy when hitting the water surface, so my idea might not be feasible. I can only place the transducer underwater.

I haven't made progress on reverse engineering the fish finder. The largest chip has no markings, and when I measured its pins with the oscilloscope, they all showed frequency-related readings. I suspect it's some kind of frequency transmitter. The other two chips are marked: one is a Bluetooth module, and the other is a filter chip. It seems there is no STM32 chip as you mentioned.

I would like to manufacture a PCB based on the one you published, but I can't seem to find the bill of materials (or perhaps I don't understand those files).

yq3w, 2025-01-08:
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
I want an intuitive 2D diagram like this, is one transducer not enough?

yq3w, 2025-01-08:
There are three test pins on the Lucky Fish Finder circuit board. TS1, TS2, TS3. Through the oscilloscope, I think TS1 is a pulse signal, TS2 is the original signal containing transmission and echo, and TS3 is the echo signal after filtering.
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
（ts1）
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
（ts2）
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
(ts3)

另外也有标记GND的触点。

yq3w, 2025-01-08:
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
This LE5010A1 is an MCU with Bluetooth

yq3w, 2025-01-08:
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

Neumi, 2025-01-08:
Thats interesting. That is a 100% new PCB design compared to my board. But it actually looks a bit cleaner now with fewer parts. Might be easier to reverse engineer...
A bit funny that they remove the microcontroller markings.
You can use T1 and T3 to read the echo using an arduino board. Actually kinda nice that they added these large test points for us :D Use T1 for a digital trigger input and T3 as the analog value. Then you can use the Arduino code I provided and plot that data on the Raspberry Pi. (Then you don't need the AD converter)

This one is the BOM file: https://github.com/Neumi/open_echo/blob/main/hardware/TUSS4470_shield/TUSS4470_shield/production/bom.csv
I ordered at JLCPCB.com check the orientation of the TUSS4470 in the assembly preview!! It's sometimes rotated.
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
yq3w, 2025-01-16:
The transducer salesperson said that this high-frequency pulse transformer is needed to drive the transducer.

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

Neumi, 2025-01-19:
Looking good! Is it possible that the transducer is flipped? they have polarity. The python plot looks a bit like it amplifies a lot of noise. How clean is the power supply? Maybe try 3 9V block batteries in series to get around 27V DC and connect it to the PCB directly on the XT30 connector (and select the right jumper). Have you checked the arduino code and made sure that the PWM works at the right frequency? The OCR1A needs to be "OCR1A = 39;" to run on 200kHz.

The 200kHz has a high resistance in air. Water works better. I only get 60-120cm echos from the 200kHz transducer when everything is set up correctly with my 200kHz DIY transducer.
If that does not help, use a transformer. You don't necessarily need MOSFETs to drive it. I just tested yesterday and had good results in water. I used this one as the 1:6 configuration: https://www.aliexpress.com/item/1005003733606845.html

I just released a new video about the current state with TUSS4470 and the transformer, but its more of an update than an instruction or how to. https://www.youtube.com/watch?v=Bxh3rWd5RZk
I'm currently developing a new board with a transformer that should make it easier to run higher-power 200kHz transducers.
Keep me posted about your progress!

yq3w, 2025-01-20:
Your reminders are always right. I found a software/development/generate_200khz_atmega328/generate_200khz_atmega328.ino in the code.

However, I found that it didn't work when I integrated the code, because this code was written for Arduino with AVR architecture (such as Arduino Uno), and the Arduino Uno R4 WiFi I bought uses a SAMD21 microcontroller, so it can't directly use the AVR registers.

I modified the code to match the Arduino Uno R4 WiFi, but I don't know if it works.

New code:

```
#include <SPI.h>

const int SPI_CS = 10;  // SPI片选引脚
const int IO1 = 8;      // IO引脚1
const int IO2 = 9;      // IO引脚2
const int O3 = 6;       // 输入引脚3
const int O4 = 5;       // 输入引脚4
const int analogIn = A0; // 模拟输入引脚

// SPI Buffers
byte misoBuf[2];  // SPI接收缓冲区
byte inByteArr[2];  // SPI发送缓冲区

const int numSamples = 100; // 采样数量
int analogValues[numSamples]; // 存储模拟值的数组

const int pwmPin = 10; // PWM 输出引脚

void setup() {
  Serial.begin(115200); // 初始化串口通信

  // 初始化SPI
  SPI.begin();

  // 设置引脚模式
  pinMode(SPI_CS, OUTPUT);
  digitalWrite(SPI_CS, HIGH);

  pinMode(IO1, OUTPUT);
  digitalWrite(IO1, HIGH);
  pinMode(IO2, OUTPUT);
  pinMode(O3, INPUT);
  pinMode(O4, INPUT);

  // 设置PWM输出
  pinMode(pwmPin, OUTPUT); // 设置引脚10为输出
  analogWrite(pwmPin, 128); // 设置占空比为50%（0-255范围）

  // 初始化TUSS4470
  tuss4470Write(0x10, 0x01);  // 设置BPF中心频率为200kHz
  tuss4470Write(0x16, 0x01);  // 启用VDRV（非高阻态）
  tuss4470Write(0x1A, 0x08);  // 设置突发脉冲为8
}

void loop() {
  // 触发时间测量
  tuss4470Write(0x1B, 0x01);
  generatePulses(8); // 生成脉冲

  // 读取模拟值
  for (int i = 0; i < numSamples; i++) {
    analogValues[i] = analogRead(analogIn);
  }

  // 停止时间测量
  tuss4470Write(0x1B, 0x00);

  // 打印采样值
  Serial.print("sp");
  for (int i = 0; i < numSamples; i++) {
    Serial.print(analogValues[i]);
    if (i < numSamples - 1) {
      Serial.print(", ");
    }
  }
  Serial.println();

  delay(100); // 延迟100毫秒
}

byte tuss4470Read(byte addr) {
  inByteArr[0] = 0x80 + ((addr & 0x3F) << 1);  // 设置读取位和地址
  inByteArr[1] = 0x00;  // 空数据字节
  spiTransfer(inByteArr, sizeof(inByteArr));

  return misoBuf[1];
}

void tuss4470Write(byte addr, byte data) {
  inByteArr[0] = (addr & 0x3F) << 1;  // 设置写入位和地址
  inByteArr[1] = data;
  spiTransfer(inByteArr, sizeof(inByteArr));
}

void spiTransfer(byte* mosi, byte sizeOfArr) {
  memset(misoBuf, 0x00, sizeof(misoBuf));

  digitalWrite(SPI_CS, LOW);
  for (int i = 0; i < sizeOfArr; i++) {
    misoBuf[i] = SPI.transfer(mosi[i]);
  }
  digitalWrite(SPI_CS, HIGH);
}

void generatePulses(int numPulses) {
  for (int i = 0; i < numPulses; i++) {
    digitalWrite(IO2, HIGH);  // 设置IO2（引脚9）为高
    delayMicroseconds(13);
    digitalWrite(IO2, LOW);   // 设置IO2为低
    delayMicroseconds(13);
  }
}

```

But I can measure the pulse waveform from the transducer interface. I guess the code is valid.

But it seems that the transducer still doesn't work well. I have purchased a transformer, which will be received in a few days.

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

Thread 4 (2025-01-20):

cINN 200 and 40 kHz labels swapped in TUSS4470 drive board version 001

Neumi, 2025-01-20:
The labels are swapped. 200kHz must be 40kHz and vice versa
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

Neumi, 2025-04-11:
fixed in HW version 2 2a44f8182ffda9f0b185a4d13648ae495c37e251

Closed 2025-04-11.

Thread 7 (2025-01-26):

Add license information

vazhnov, 2025-01-26:
Hello!

I found this amazing project from https://hackaday.com/2025/01/24/setting-the-stage-for-open-source-sonar-development/

Could you please add information about the license of this repository — is it allowed to copy, change and use the code, documentation and PCB hardware files in any purpose?
It would be great to see any popular open source license.

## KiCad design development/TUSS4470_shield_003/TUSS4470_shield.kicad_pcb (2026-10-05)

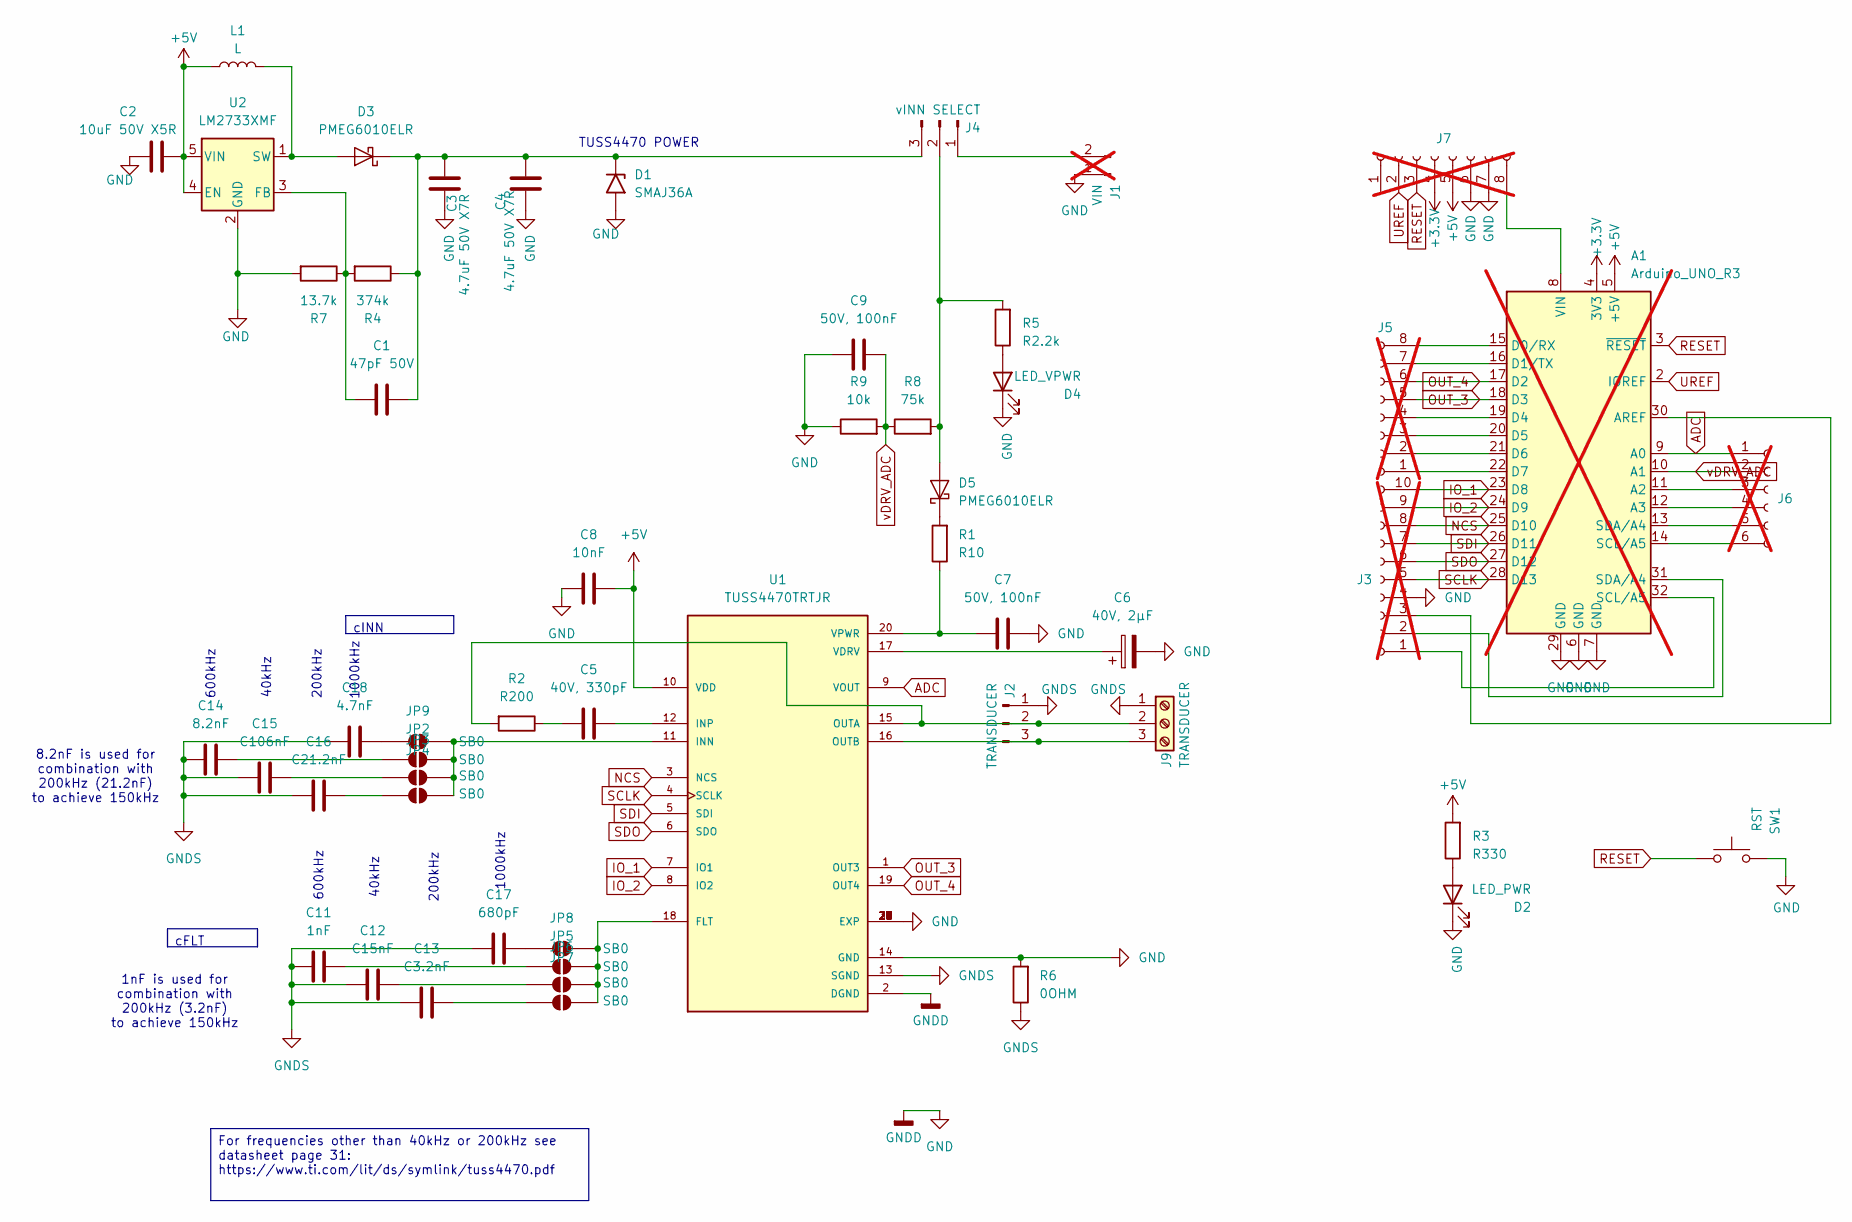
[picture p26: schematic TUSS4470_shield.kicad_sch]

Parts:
A1: Arduino_UNO_R3; not fitted
C1: 47pF 50V; R_0603_1608Metric; LCSC C1671
C2: 10uF 50V X5R; C_1206_3216Metric; LCSC C13585
C3, C4: 4.7uF 50V X7R; C_1206_3216Metric; LCSC C29823
C5: 40V, 330pF; C_0603_1608Metric; LCSC C1664
C6: 40V, 2µF; C_1206_3216Metric; LCSC C50254
C7, C9: 50V, 100nF; C_0603_1608Metric; LCSC C14663
C8: 10nF; C_0603_1608Metric; LCSC C57112
C11: 1nF; C_0603_1608Metric; LCSC C1588
C12: C15nF; C_0603_1608Metric; LCSC C1596
C13: C3.2nF; C_0603_1608Metric; LCSC C1613
C14: 8.2nF; C_0603_1608Metric; LCSC C1322360
C15: C106nF; C_0603_1608Metric; LCSC C14663
C16: C21.2nF; C_0603_1608Metric; LCSC C21122
C17: 680pF; C_0603_1608Metric; LCSC C1630
C18: 4.7nF; C_0603_1608Metric; LCSC C53987
D1: SMAJ36A; D_SMA; LCSC C19077550
D2: LED_PWR; LED_0805_2012Metric; LCSC C84256
D3, D5: PMEG6010ELR; Nexperia_CFP3_SOD-123W; LCSC C179432
D4: LED_VPWR; LED_0805_2012Metric; LCSC C84256
J1: VIN; AMASS_XT30PW-M_1x02_P2.50mm_Horizontal; LCSC C431092; not fitted
J2: TRANSDUCER; PinHeader_1x03_P2.54mm_Vertical
J3: Conn_01x10_Socket; PinHeader_1x10_P2.54mm_Vertical; not fitted
J4: vINN SELECT; PinHeader_1x03_P2.54mm_Vertical; LCSC C49257
J5, J7: Conn_01x08_Socket; PinHeader_1x08_P2.54mm_Vertical; not fitted
J6: Conn_01x06_Socket; PinHeader_1x06_P2.54mm_Vertical; not fitted
J9: TRANSDUCER; TerminalBlock_4Ucon_1x03_P3.50mm_Horizontal
JP2, JP3, JP4, JP5, JP6, JP7, JP8, JP9: SB0; SolderJumper-2_P1.3mm_Open_RoundedPad1.0x1.5mm
L1: L; L_Taiyo-Yuden_NR-60xx; LCSC C16218
R1: R10; R_1206_3216Metric; LCSC C17903
R2: R200; R_1206_3216Metric; LCSC C25361
R3: R330; R_0603_1608Metric; LCSC C23138
R4: 374k; R_0603_1608Metric; LCSC C25815
R5: R2.2k; R_0603_1608Metric; LCSC C4190
R6: 0OHM; R_0805_2012Metric; LCSC C17477
R7: 13.7k; R_0603_1608Metric; LCSC C325658
R8: 75k; R_0603_1608Metric; LCSC C23242
R9: 10k; R_0603_1608Metric; LCSC C25804
SW1: RST; SW_Push_1P1T_NO_CK_KSC7xxJ; LCSC C318884
U1: TUSS4470TRTJR; QFN-20-1EP_4x4mm_P0.5mm_EP2.5x2.5mm_ThermalVias; PARTREV December 2019; LCSC C1855776
U2: LM2733XMF; SOT-23-5

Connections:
+3.3V: A1.4 (3V3), J7.4
+5V: A1.5 (+5V), C2.2, C8.2, J7.5, L1.1, R3.2, U1.10 (VDD), U2.4 (EN), U2.5 (VIN)
ADC: A1.9 (A0), J6.1, U1.9 (VOUT)
GND: A1.6 (GND), A1.7 (GND), A1.29 (GND), C2.1, C3.1, C4.1, C6.2, C7.2, C8.1, C9.1, D1.2 (A2), D2.1 (K), D4.1 (K), J1.1, J3.4, J7.6, J7.7, R6.2, R7.2, R9.1, SW1.2, U1.2 (DGND), U1.14 (GND), U1.21 (EXP), U1.22 (EXP), U1.23 (EXP), U1.24 (EXP), U1.25 (EXP), U1.26 (EXP), U1.27 (EXP), U1.28 (EXP), U1.29 (EXP), U1.30 (EXP), U2.2 (GND)
GNDS: C11.1, C12.1, C13.1, C14.1, C15.1, C16.1, C17.1, C18.1, J2.1, J9.1, R6.1, U1.13 (SGND)
IO_1: A1.23 (D8), J3.10, U1.7 (IO1)
IO_2: A1.24 (D9), J3.9, U1.8 (IO2)
NCS: A1.25 (D10), J3.8, U1.3 (NCS)
unnamed: A1.11 (A2), J6.3
unnamed: A1.12 (A3), J6.4
unnamed: A1.30 (AREF), J3.3
unnamed: A1.15 (D0/RX), J5.8
unnamed: A1.16 (D1/TX), J5.7
unnamed: A1.19 (D4), J5.4
unnamed: A1.20 (D5), J5.3
unnamed: A1.21 (D6), J5.2
unnamed: A1.22 (D7), J5.1
unnamed: A1.8 (VIN), J7.8
unnamed: C5.1, R2.1
unnamed: C1.2, C3.2, C4.2, D1.1 (A1), D3.1 (K), J4.3, R4.1
unnamed: D2.2 (A), R3.1
unnamed: D3.2 (A), L1.2, U2.1 (SW)
unnamed: D4.2 (A), R5.1
unnamed: D5.2 (A), J4.2, R5.2, R8.2
unnamed: D5.1 (K), R1.2
unnamed: J1.2, J4.1
unnamed: J2.2, J9.2, R2.2, U1.15 (OUTA)
unnamed: J2.3, J9.3, U1.16 (OUTB)
unnamed: A1.32 (SCL/A5), J3.1
unnamed: A1.31 (SDA/A4), J3.2
unnamed: A1.13 (SDA/A4), J6.5
unnamed: A1.14 (SCL/A5), J6.6
unnamed: C14.2, JP2.1 (A)
unnamed: JP2.2 (B), JP3.2 (B), JP4.2 (B), JP9.2 (B), U1.11 (INN)
unnamed: C15.2, JP3.1 (A)
unnamed: C16.2, JP4.1 (A)
unnamed: C11.2, JP5.1 (A)
unnamed: JP5.2 (B), JP6.2 (B), JP7.2 (B), JP8.2 (B), U1.18 (FLT)
unnamed: C12.2, JP6.1 (A)
unnamed: C13.2, JP7.1 (A)
unnamed: C17.2, JP8.1 (A)
unnamed: C18.2, JP9.1 (A)
unnamed: C5.2, U1.12 (INP)
unnamed: C6.1, U1.17 (VDRV)
unnamed: C7.1, R1.1, U1.20 (VPWR)
unnamed: C1.1, R4.2, R7.1, U2.3 (FB)
OUT_3: A1.18 (D3), J5.5, U1.1 (OUT3)
OUT_4: A1.17 (D2), J5.6, U1.19 (OUT4)
RESET: A1.3 (~RESET), J7.3, SW1.1
SCLK: A1.28 (D13), J3.5, U1.4 (SCLK)
SDI: A1.26 (D11), J3.7, U1.5 (SDI)
SDO: A1.27 (D12), J3.6, U1.6 (SDO)
UREF: A1.2 (IOREF), J7.2
vDRV_ADC: A1.10 (A1), C9.2, J6.2, R8.1, R9.2

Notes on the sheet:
200kHz
40kHz
8.2nF is used for combination with 200kHz (21.2nF) to achieve 150kHz
600kHz
1nF is used for combination with 200kHz (3.2nF) to achieve 150kHz
1000kHz
TUSS4470 POWER
cFLT
For frequencies other than 40kHz or 200kHz see datasheet page 31: https://www.ti.com/lit/ds/symlink/tuss4470.pdf
cINN

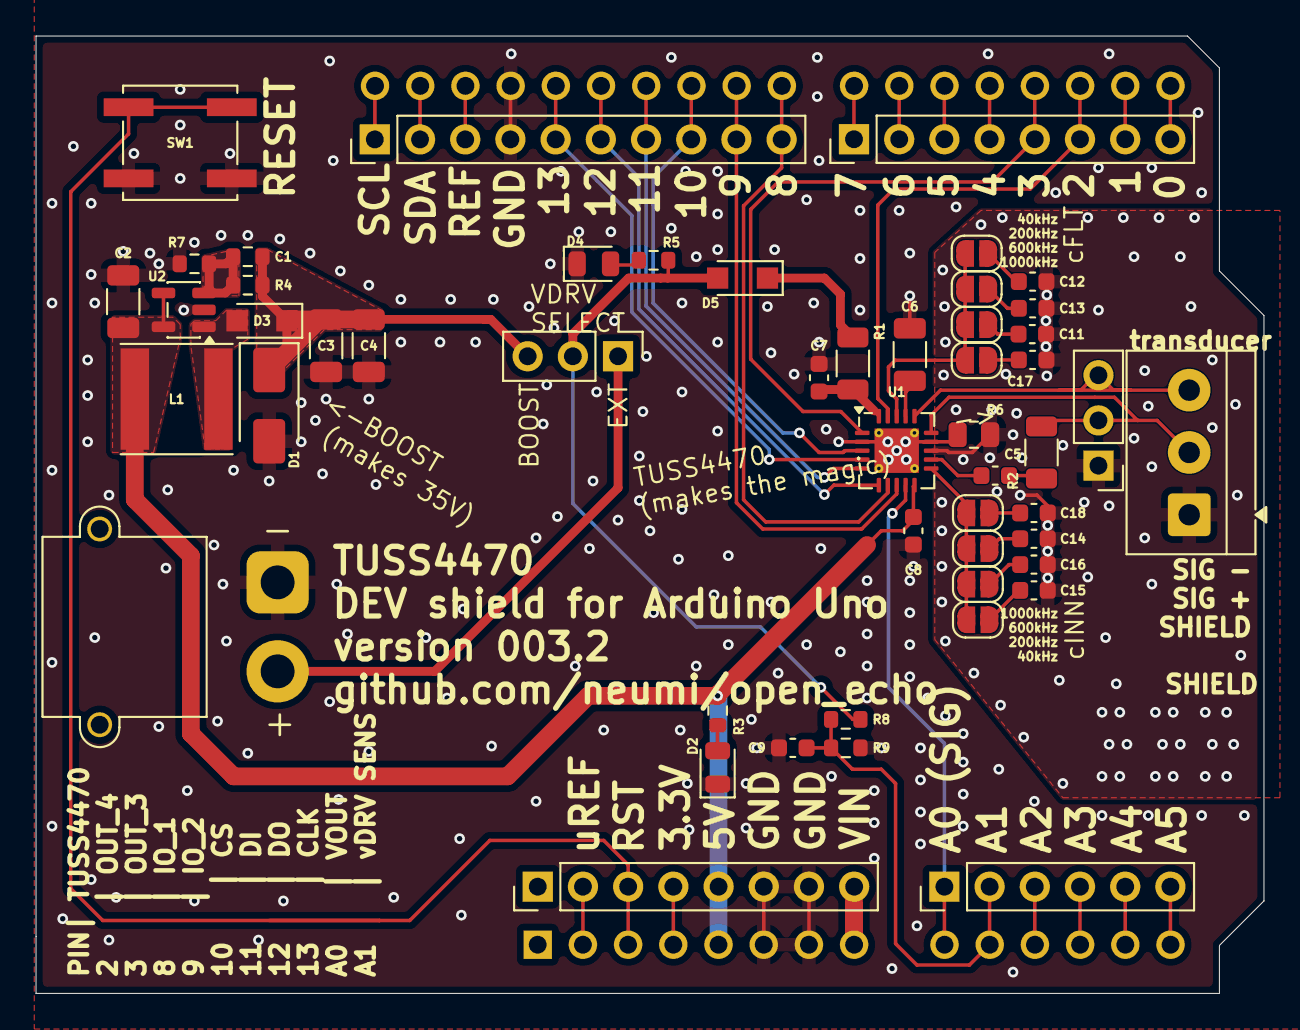
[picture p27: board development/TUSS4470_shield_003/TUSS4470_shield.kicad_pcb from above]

Board: 2 copper layers, 69.0 x 53.8 mm, 52 parts (1 on the bottom side), 54 nets.

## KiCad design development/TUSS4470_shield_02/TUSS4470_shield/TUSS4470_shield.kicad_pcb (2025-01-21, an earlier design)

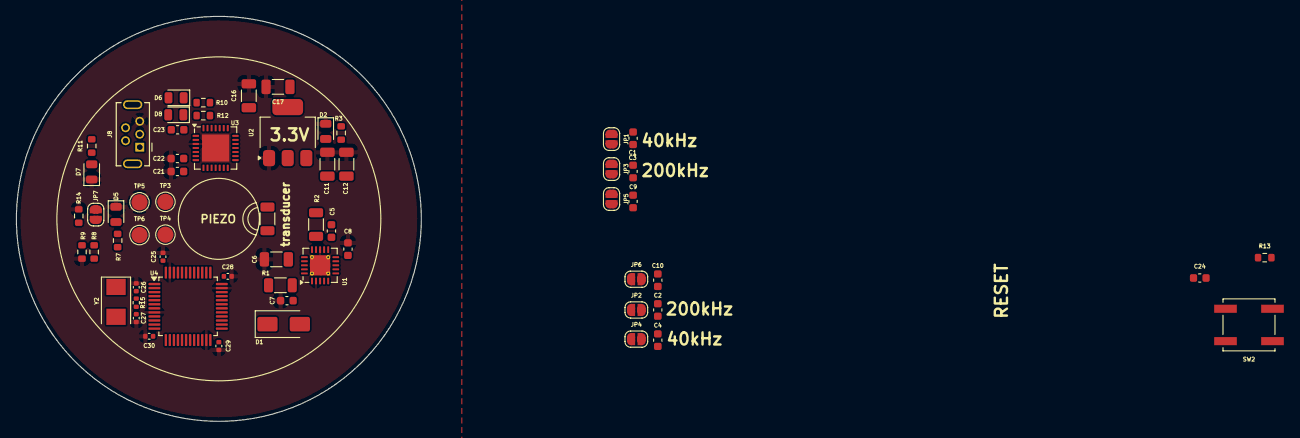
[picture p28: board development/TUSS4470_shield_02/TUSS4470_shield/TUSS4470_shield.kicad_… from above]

Board: 2 copper layers, 50.0 x 50.0 mm, 61 parts (0 on the bottom side), 36 nets, no tracks yet.

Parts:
C1: C15nF; C_0603_1608Metric
C2: C106nF; C_0603_1608Metric
C3: C3.2nF; C_0603_1608Metric
C4: C21.2nF; C_0603_1608Metric
C5: 40V, 330pF; C_0603_1608Metric
C6: 40V, 2µF; C_1206_3216Metric
C7: 50V, 100nF; C_0603_1608Metric
C8: 10nF; C_0603_1608Metric
C9, C10: CXXnF; C_0603_1608Metric
C11, C16: C100nF; C_1206_3216Metric
C12, C17: C47uF; C_1206_3216Metric
C21, C22, C23, C24: C100nF; C_0603_1608Metric
C25, C28, C29, C30: C100nF; C_0402_1005Metric
C26, C27: C22pF; C_0402_1005Metric
D1: 1N4001; D_SMA
D2: LED_PWR; LED_0805_2012Metric
D5: LED_PC13; LED_0805_2012Metric
D6: TX; LED_0805_2012Metric
D7: LED_3.3V_PWR; LED_0805_2012Metric
D8: RX; LED_0805_2012Metric
J8: USB_B_Mini; USB_Mini-B_Tensility_54-00023_Vertical
JP1, JP2: 40kHz; SolderJumper-2_P1.3mm_Open_RoundedPad1.0x1.5mm
JP3, JP4: 200kHz; SolderJumper-2_P1.3mm_Open_RoundedPad1.0x1.5mm
JP5, JP6: CUSTOM kHz; SolderJumper-2_P1.3mm_Open_RoundedPad1.0x1.5mm
JP7: termination_jumper; SolderJumper-2_P1.3mm_Open_RoundedPad1.0x1.5mm
R1: R10; R_1206_3216Metric
R2: R200; R_1206_3216Metric
R3, R10, R11, R12: R330; R_0603_1608Metric
R7, R8, R9: R1k; R_0603_1608Metric
R13, R14: R10k; R_0603_1608Metric
R15: R1M; R_0402_1005Metric
SW2: RST; SW_Push_1P1T_NO_CK_KSC7xxJ
TP3: RX; TestPoint_Pad_D2.0mm
TP4: TX; TestPoint_Pad_D2.0mm
TP5: GND; TestPoint_Pad_D2.0mm
TP6: 3.3V; TestPoint_Pad_D2.0mm
U1: TUSS4470TRTJR; QFN-20-1EP_4x4mm_P0.5mm_EP2.5x2.5mm_ThermalVias
U2: AMS1117-3.3; SOT-223-3_TabPin2
U3: CP2102N-A01-GQFN28; QFN-28-1EP_5x5mm_P0.5mm_EP3.35x3.35mm
U4: STM32F103C8Tx; LQFP-48_7x7mm_P0.5mm
Y1: Crystal; R_1206_3216Metric
Y2: Crystal; Crystal_SMD_5032-2Pin_5.0x3.2mm

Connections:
5V_voltage_detect: R8.2, R9.1, U4.19 (PB1)
+3.3V: C16.1, C17.1, C25.1, C28.1, C29.1, C30.1, D6.2 (A), D8.2 (A), JP7.2 (B), R11.2, R13.1, TP6.1, U2.2 (VO), U4.9 (VDDA), U4.24 (VDD), U4.36 (VDD), U4.48 (VDD)
+5V: C8.2, C11.1, C12.1, R3.2, R8.1, U1.10 (VDD), U2.3 (VI)
BOOT_0: JP7.1 (A), R14.1, U4.44 (BOOT0)
GND: C1.2, C2.2, C3.2, C4.2, C6.2, C7.2, C8.1, C9.2, C10.2, C11.2, C12.2, C16.2, C17.2, C21.1, C22.1, C24.2, C25.2, C26.1, C27.2, C28.2, C29.2, C30.2, D2.1 (K), D5.1 (K), D7.1 (K), J8.5 (GND), R9.2, R14.2, SW2.2, TP5.1, U1.2 (DGND), U1.13 (SGND), U1.14 (GND), U1.21 (EXP), U2.1 (GND), U3.3 (GND), U3.29 (GND), U4.8 (VSSA), U4.23 (VSS), U4.35 (VSS), U4.47 (VSS)
unnamed: C5.1, R2.1
unnamed: D1.1 (K), R1.2
unnamed: D2.2 (A), R3.1
unnamed: D5.2 (A), R7.1
unnamed: D6.1 (K), R10.1
unnamed: D7.2 (A), R11.1
unnamed: D8.1 (K), R12.1
unnamed: J8.3 (D+), U3.4 (D+)
unnamed: J8.2 (D-), U3.5 (D-)
unnamed: C21.2, J8.1 (VBUS), U3.7 (REGIN), U3.8 (VBUS)
unnamed: C1.1, JP1.1 (A)
unnamed: JP1.2 (B), JP3.2 (B), JP5.2 (B), U1.18 (FLT)
unnamed: C2.1, JP2.1 (A)
unnamed: JP2.2 (B), JP4.2 (B), JP6.2 (B), U1.11 (INN)
unnamed: C3.1, JP3.1 (A)
unnamed: C4.1, JP4.1 (A)
unnamed: C9.1, JP5.1 (A)
unnamed: C10.1, JP6.1 (A)
unnamed: C5.2, U1.12 (INP)
unnamed: R2.2, U1.15 (OUTA), Y1.2
unnamed: U1.16 (OUTB), Y1.1
unnamed: C6.1, U1.17 (VDRV)
unnamed: C7.1, R1.1, U1.20 (VPWR)
unnamed: C22.2, U3.6 (VDD)
unnamed: C23.1, U3.28 (~DTR)
unnamed: R7.2, U4.2 (PC13-TAMPER-RTC)
unnamed: C26.2, R15.1, U4.5 (PD0-OSC_IN), Y2.1
unnamed: C27.1, R15.2, U4.6 (PD0-OSC_OUT), Y2.2
rst: C23.2, C24.1, R13.2, SW2.1, U4.7 (NRST)
uC_RX: R12.2, TP3.1, U3.26 (TXD), U4.31 (PA10)
uC_TX: R10.2, TP4.1, U3.25 (RXD), U4.30 (PA9)

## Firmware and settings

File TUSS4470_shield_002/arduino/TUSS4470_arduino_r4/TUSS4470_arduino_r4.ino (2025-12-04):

#include "settings.h"
#include <SPI.h>
#include <SoftwareSerial.h>

#include <Arduino.h>
#include <FspTimer.h>
#if WIFI_ENABLED
  #include <WiFiS3.h>
  #include "wifi_server.h"
#endif

// Pin configuration
const int SPI_CS = 10;
const int IO1 = 8;
const int IO2 = 9;
const int O3 = 3;
const int O4 = 2;
const int analogIn = A0;
const int nmeaTx = 4;
const int nmeaRx = 5;

SoftwareSerial nmeaSerial(nmeaRx, nmeaTx); 

// ---------------------- ADC SETUP FOR ARDUINO R4 ----------------------
// Defines addresses and convenience functions for RA4M1 ADC
// Base addresses for ADC (from RA4M1 hardware manual)
// Taken from https://github.com/TriodeGirl/Arduino-UNO-R4-code-DAC-ADC-Ints-Fast_Pins/blob/main/Arduino_UNO_R4_Interrupts_ADC_and_DAC_1.ino
#define MSTP_BASE   0x40040000u
#define MSTPCRD    (*(volatile uint32_t *)(MSTP_BASE + 0x7008u))

#define ADC_BASE    0x40050000u
#define ADCSR      (*(volatile uint16_t *)(ADC_BASE + 0xC000u))
#define ADANSA0    (*(volatile uint16_t *)(ADC_BASE + 0xC004u))
#define ADCER      (*(volatile uint16_t *)(ADC_BASE + 0xC00Eu))
#define ADSTRGR    (*(volatile uint16_t *)(ADC_BASE + 0xC010u)) // Not currently used, could be used to trigger ADC from timer. If combined with DMA, could be even faster.
#define ADDR09     (*(volatile uint16_t *)(ADC_BASE + 0xC020u + 18)) // channel AN09 (A0 pin)


struct __attribute__((packed)) Frame {
  uint8_t  start = 0xAA;
  uint16_t  depth_index;            
  int16_t  temp_scaled;     
  uint16_t vDrv_scaled;     
  uint8_t  samples[NUM_SAMPLES];
  uint8_t  checksum;         
};

static Frame frame;  // Data frame to send over WebSocket
static uint8_t samplesXor = 0;   // Accumulate XOR while sampling

byte misoBuf[2];  // SPI receive buffer
byte inByteArr[2];  // SPI transmit buffer

volatile int pulseCount = 0;
volatile int sampleIndex = 0;

float temperature = 0.0f;
int vDrv = 0;

volatile bool detectedDepth = false;  // Condition flag
volatile uint16_t depthDetectSample = 0;

// --- Burst Control Timer ---
FspTimer burstTimer;

void burstCallback(timer_callback_args_t *) {
  digitalWrite(IO2, !digitalRead(IO2));
  pulseCount++;
  if (pulseCount >= 32) {
    burstTimer.stop();
    pulseCount = 0;  // Reset counter for next cycle
  }
}

byte tuss4470Read(byte addr) {
  inByteArr[0] = 0x80 + ((addr & 0x3F) << 1);  // Set read bit and address
  inByteArr[1] = 0x00;  // Empty data byte
  inByteArr[0] |= tuss4470Parity(inByteArr);
  spiTransfer(inByteArr, sizeof(inByteArr));

  return misoBuf[1];
}

void tuss4470Write(byte addr, byte data) {
  inByteArr[0] = (addr & 0x3F) << 1;  // Set write bit and address
  inByteArr[1] = data;
  inByteArr[0] |= tuss4470Parity(inByteArr);
  spiTransfer(inByteArr, sizeof(inByteArr));
}

byte tuss4470Parity(byte* spi16Val) {
  return parity16(BitShiftCombine(spi16Val[0], spi16Val[1]));
}

void spiTransfer(byte* mosi, byte sizeOfArr) {
  memset(misoBuf, 0x00, sizeof(misoBuf));

  digitalWrite(SPI_CS, LOW);
  for (int i = 0; i < sizeOfArr; i++) {
    misoBuf[i] = SPI.transfer(mosi[i]);
  }
  digitalWrite(SPI_CS, HIGH);
}

unsigned int BitShiftCombine(unsigned char x_high, unsigned char x_low) {
  return (x_high << 8) | x_low;  // Combine high and low bytes
}

byte parity16(unsigned int val) {
  byte ones = 0;
  for (int i = 0; i < 16; i++) {
    if ((val >> i) & 1) {
      ones++;
    }
  }
  return (ones + 1) % 2;  // Odd parity calculation
}

void handleInterrupt() {
  if (!detectedDepth) {
    depthDetectSample = sampleIndex;
    detectedDepth = true;
  }
}

void setup()
{
  Serial.begin(250000);
  nmeaSerial.begin(NMEA_BAUD_RATE);

  SPI.begin();
  SPI.beginTransaction(SPISettings(1000000, MSBFIRST, SPI_MODE1)); 
  #if WIFI_ENABLED
    wifiSetup(WIFI_SSID, WIFI_PASS);
  #endif

  pinMode(SPI_CS, OUTPUT);
  digitalWrite(SPI_CS, HIGH);

  // Configure GPIOs
  pinMode(IO1, OUTPUT);
  digitalWrite(IO1, HIGH);
  pinMode(IO2, OUTPUT);
  pinMode(O4, INPUT_PULLUP);
  attachInterrupt(digitalPinToInterrupt(O4), handleInterrupt, RISING);

  // Initialize TUSS4470 with specific configurations
  // check TUSS4470 datasheet for more settings!
  tuss4470Write(0x10, FILTER_FREQUENCY_REGISTER);  // Set BPF center frequency
  tuss4470Write(0x16, 0xF);  // Enable VDRV (not Hi-Z)
  tuss4470Write(0x1A, 0x0F);  // Set burst pulses to 16
  tuss4470Write(0x17, THRESHOLD_VALUE); // enable threshold detection on OUT_4

  // Set up timer for transducer burst
  uint8_t timerType = GPT_TIMER;                 // get_available_timer needs a modifiable lvalue reference
  uint8_t channel = FspTimer::get_available_timer(timerType); // returns -1 if none available
  burstTimer.begin(TIMER_MODE_PERIODIC, timerType, channel, DRIVE_FREQUENCY * 2, 0.0f, burstCallback);
  burstTimer.setup_overflow_irq();
  burstTimer.open();

  // Set up ADC
  MSTPCRD &= ~(1u << 16);// Enable module
  ADANSA0 = (1u << 9); // Select channel AN09 only
  ADCER = 0x0000;// 12-bit, right align (ADCER default is fine; set explicitly = 0)
  ADCSR &= ~(1u << 5); // Software trigger mode (TRGE=0), single scan (ADCS=00)
}

void loop()
{
  // Trigger time-of-flight measurement
  tuss4470Write(0x1B, 0x01);

  burstTimer.start();

  //int startTime = micros();

  // Read analog values from A0
  for (sampleIndex = 0; sampleIndex < NUM_SAMPLES; sampleIndex++) {
    ADCSR |= (1u << 15);        // Set ADST (start)
    while (ADCSR & (1u << 15));  // Wait while ADST remains 1
    uint8_t v = ADDR09 >> 4; // Read ADC value, 12 bit >> 8 bit
    frame.samples[sampleIndex] = v;

    delayMicroseconds(11.5);

    if (sampleIndex == BLINDZONE_SAMPLE_END) {
      detectedDepth = false;
    }
  }
  //int runTime = micros() - startTime;

  // Stop time-of-flight measurement
  tuss4470Write(0x1B, 0x00);
  
  // Software depth override
  #if USE_DEPTH_OVERRIDE
  int overrideSample = 0;
  uint8_t max = 0;
  for (int i = BLINDZONE_SAMPLE_END; i < NUM_SAMPLES; i++) {
    if (frame.samples[i] > max) {
      max = frame.samples[i];
      overrideSample = i;
    }
  }
  if (overrideSample > 0) {
    depthDetectSample = overrideSample;
  }
  #endif
  
  sendNmeaDBT();
  sendData();

  // delay(10);
}

void sendData() {
  // Header fields
  frame.depth_index = depthDetectSample;

  frame.temp_scaled = (int16_t)(temperature * 100.0f);
  frame.vDrv_scaled = (uint16_t)(vDrv * 100);

  // Compute checksum (XOR of depth bytes, temp bytes, vDrv bytes, all samples)
  uint8_t cs = 0;
  // depth
  cs ^= (uint8_t)(frame.depth_index & 0xFF);
  cs ^= (uint8_t)(frame.depth_index >> 8);
  // temp
  cs ^= (uint8_t)(frame.temp_scaled & 0xFF);
  cs ^= (uint8_t)(frame.temp_scaled >> 8);
  // vDrv
  cs ^= (uint8_t)(frame.vDrv_scaled & 0xFF);
  cs ^= (uint8_t)(frame.vDrv_scaled >> 8);
  // samples
  for (int i = 0; i < NUM_SAMPLES; i++) {
    cs ^= frame.samples[i];
  }
  frame.checksum = cs;

  // Total length (packed, known)
  const size_t len = 1 + 2 + 2 + 2 + NUM_SAMPLES + 1;

  Serial.write(reinterpret_cast<uint8_t*>(&frame), len);

  #if WIFI_ENABLED && ENABLE_UDP_ECHO
    udpBroadcastBIN(reinterpret_cast<uint8_t*>(&frame), len, UDP_ECHO_PORT);
  #endif
}


void sendNmeaDBT() {
  // Calculate depth in meters
  float time_of_flight = depthDetectSample * 13.2e-6f;
  float depth_m = (time_of_flight * 1450.0f) / 2.0f;

  float depth_ft = depth_m * 3.28084f;
  float depth_fa = depth_m / 1.8288f;

  // Convert floats to strings
  char str_ft[10], str_m[10], str_fa[10];
  dtostrf(depth_ft, 4, 1, str_ft);
  dtostrf(depth_m, 4, 1, str_m);
  dtostrf(depth_fa, 4, 1, str_fa);

  // Trim leading spaces (manually)
  char* ptr_ft = str_ft;
  char* ptr_m = str_m;
  char* ptr_fa = str_fa;
  while (*ptr_ft == ' ') ptr_ft++;
  while (*ptr_m == ' ') ptr_m++;
  while (*ptr_fa == ' ') ptr_fa++;

  // Build the NMEA DBT sentence
  char dbt_sentence[80];
  snprintf(dbt_sentence, sizeof(dbt_sentence),
           "$SDDBT,%s,f,%s,M,%s,F", ptr_ft, ptr_m, ptr_fa);

  // Calculate checksum (XOR of chars between $ and *)
  uint8_t dbt_checksum = 0;
  for (int i = 1; dbt_sentence[i] != '\0'; i++) {
    dbt_checksum ^= dbt_sentence[i];
  }

  // Final output with checksum
  char fullDBTSentence[90];
  snprintf(fullDBTSentence, sizeof(fullDBTSentence), "%s*%02X\r\n", dbt_sentence, dbt_checksum);

  nmeaSerial.print(fullDBTSentence);
  #if WIFI_ENABLED && ENABLE_UDP_NMEA
    udpBroadcastNMEA(fullDBTSentence, strlen(fullDBTSentence), UDP_NMEA_PORT);
  #endif

  // Build the NMEA DPT sentence
  char str_offset[10];
  dtostrf(DEPTH_OFFSET, 4, 1, str_offset);
  char* ptr_offset = str_offset;
  while (*ptr_offset == ' ') ptr_offset++;

  // We are (possibly optimistically) reporting max depth of 100m
  char dpt_sentence[80];
  snprintf(dpt_sentence, sizeof(dpt_sentence),
           "$SDDPT,%s,%s,100", ptr_m, ptr_offset);

  // Calculate checksum (XOR of chars between $ and *)
  uint8_t dpt_checksum = 0;
  for (int i = 1; dpt_sentence[i] != '\0'; i++) {
    dpt_checksum ^= dpt_sentence[i];
  }

  // Final output with checksum
  char fullDPTSentence[90];
  snprintf(fullDPTSentence, sizeof(fullDPTSentence), "%s*%02X\r\n", dpt_sentence, dpt_checksum);

  nmeaSerial.print(fullDPTSentence);
  #if WIFI_ENABLED && ENABLE_UDP_NMEA
    udpBroadcastNMEA(fullDPTSentence, strlen(fullDPTSentence), UDP_NMEA_PORT);
  #endif
}

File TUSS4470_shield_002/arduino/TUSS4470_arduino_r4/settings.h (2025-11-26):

#pragma once

#include <Arduino.h>

// ---------------------- DRIVE FREQUENCY SETTINGS ----------------------
// Sets the output frequency of the ultrasonic transducer
// Uses DRIVE_FREQUENCY directly for R4, uses divider for R3
#define DRIVE_FREQUENCY 40000
const int DRIVE_FREQUENCY_TIMER_DIVIDER = (16000000 / (2 * DRIVE_FREQUENCY)) - 1;

// ---------------------- BANDPASS FILTER SETTINGS ----------------------
// Sets the digital band-pass filter frequency on the TUSS4470 driver chip
// This should roughly match the transducer drive frequency
// For additional register values, see TUSS4470 datasheet, Table 7.1 (pages 17–18)
#define FILTER_FREQUENCY_REGISTER 0x00 // 40 kHz
// #define FILTER_FREQUENCY_REGISTER 0x09 // 68 kHz
// #define FILTER_FREQUENCY_REGISTER 0x10 // 100 kHz
// #define FILTER_FREQUENCY_REGISTER 0x18 // 151 kHz
// #define FILTER_FREQUENCY_REGISTER 0x1E // 200 kHz

// Number of ADC samples to take per measurement cycle
// Each sample takes approximately 13.2 microseconds
// This value must match the number of samples expected by the Python visualization tool
// Max 1800 on R3, ~10000 on R4
#define NUM_SAMPLES 1800

// Number of initial samples to ignore after sending the transducer pulse
// These ignored samples represent the "blind zone" where the transducer is still ringing
#define BLINDZONE_SAMPLE_END 450

// Threshold level for detecting the bottom echo
// The first echo stronger than this value (after the blind zone) is considered the bottom
#define THRESHOLD_VALUE 0x19

  
// ---------------------- DEPTH OVERRIDE ----------------------
// If enabled, software will scan the captured analogValues[] after each
// acquisition and choose the max sample after the blind zone to be 
// the bottom echo, instead of the first sample above the threshold.
#define USE_DEPTH_OVERRIDE 1


// ---------------------- NMEA SETTINGS ----------------------
// Fast or slow baud rate for NMEA output on SoftwareSerial (pin 4)
#define NMEA_BAUD_RATE 4800
// #define NMEA_BAUD_RATE 38400

// Depth offset in meters to add to all reported depths (can be negative)
#define DEPTH_OFFSET 0.0f

// ---------------------- WIFI SETTINGS ----------------------
// Only required for Arduino R4 WiFi
#define WIFI_ENABLED 1

static const char WIFI_SSID[] = "Your SSID";
static const char WIFI_PASS[] = "Your Password";

// ---------------------- UDP BROADCAST SETTINGS ----------------------
// Enable/disable UDP broadcast of the binary frame (same payload as Serial / WebSocket)
// This cannot be sent to all, so a specific broadcast IP must be set
#define ENABLE_UDP_ECHO 1
#define UDP_ECHO_PORT 31338
static const IPAddress UDP_ECHO_IP(10, 17, 20, 117);

#define ENABLE_UDP_NMEA 0
#define UDP_NMEA_PORT 31337

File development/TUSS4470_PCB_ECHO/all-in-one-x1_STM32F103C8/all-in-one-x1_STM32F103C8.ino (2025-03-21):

#include "Arduino.h"
#include <SPI.h>
#include <OneWire.h>
#include <DallasTemperature.h>
#include "stm32f1xx.h"


#define ANALOG_IN_PIN PB0  // ADC Channel 0
#define NUM_SAMPLES 2500
#define ANALOG_IN_CHANNEL 8  // PB0 -> ADC1_IN8
#define BLINDZONE_SAMPLE_END 25

uint16_t analogValues[NUM_SAMPLES];

const int SPI_CS = PB1;
const int IO1 = PA12;
const int IO2 = PA11;
const int O3 = PB12;
const int O4 = PB13;
const int analogIn = PB0;
#define ONE_WIRE_BUS PB3


byte misoBuf[2];  // SPI receive buffer
byte inByteArr[2];  // SPI transmit buffer

volatile int pulseCount = 0;

volatile int sampleIndex = 0;

const int interruptPin = 3;  // Pin for external interrupt
volatile bool detectedDepth = false;  // Condition flag
volatile int depthDetectSample = 0;

float temperature = 0.0f;

volatile bool interruptTriggered = false;

unsigned long lastReadTime = 0;
const long interval = 3000;  // Read temperature every 3000ms

OneWire oneWire(ONE_WIRE_BUS);
DallasTemperature sensors(&oneWire);
HardwareTimer timer(TIM1);

void generateBurst(int pulses) {
  int frequency = 200000;  // 200 kHz
  int period = 1000000 / frequency;  // 5 µs period

  // Configure the timer for PWM mode on Channel 4 (PA11)
  timer.pause();
  timer.setMode(4, TIMER_OUTPUT_COMPARE_PWM1, IO2); // Channel 4 for PA11
  timer.setPrescaleFactor(72);  // STM32F103 runs at 72 MHz → 72 prescaler = 1 MHz timer clock
  timer.setOverflow(period, MICROSEC_FORMAT);  // Set period to 5 µs
  timer.setCaptureCompare(4, period / 2, MICROSEC_COMPARE_FORMAT);  // 50% duty cycle
  timer.resume();

  // Wait for the required number of pulses (burst)
  delayMicroseconds(pulses * period);

  // Stop PWM after the burst
  timer.pause();
  digitalWrite(IO2, HIGH);  // Ensure the pin goes LOW after burst

}


byte tuss4470Read(byte addr) {
  inByteArr[0] = 0x80 + ((addr & 0x3F) << 1);  // Set read bit and address
  inByteArr[1] = 0x00;  // Empty data byte
  inByteArr[0] |= tuss4470Parity(inByteArr);
  spiTransfer(inByteArr, sizeof(inByteArr));

  return misoBuf[1];
}

void tuss4470Write(byte addr, byte data) {
  inByteArr[0] = (addr & 0x3F) << 1;  // Set write bit and address
  inByteArr[1] = data;
  inByteArr[0] |= tuss4470Parity(inByteArr);
  spiTransfer(inByteArr, sizeof(inByteArr));
}

byte tuss4470Parity(byte* spi16Val) {
  return parity16(BitShiftCombine(spi16Val[0], spi16Val[1]));
}

void spiTransfer(byte* mosi, byte sizeOfArr) {
  memset(misoBuf, 0x00, sizeof(misoBuf));

  digitalWrite(SPI_CS, LOW);
  for (int i = 0; i < sizeOfArr; i++) {
    misoBuf[i] = SPI.transfer(mosi[i]);
  }
  digitalWrite(SPI_CS, HIGH);
}

unsigned int BitShiftCombine(unsigned char x_high, unsigned char x_low) {
  return (x_high << 8) | x_low;  // Combine high and low bytes
}

byte parity16(unsigned int val) {
  byte ones = 0;
  for (int i = 0; i < 16; i++) {
    if ((val >> i) & 1) {
      ones++;
    }
  }
  return (ones + 1) % 2;  // Odd parity calculation
}



void handleInterrupt() {
  if (!detectedDepth) {
    depthDetectSample = sampleIndex;
    detectedDepth = true;
  }
}


void setup() {
  Serial1.begin(921600);
  SPI.begin();
  SPI.setBitOrder(MSBFIRST);
  SPI.setClockDivider(SPI_CLOCK_DIV16);
  SPI.setDataMode(SPI_MODE1);  // CPOL=0, CPHA=1


  pinMode(SPI_CS, OUTPUT);
  digitalWrite(SPI_CS, HIGH);

  // Configure GPIOs
  pinMode(IO1, OUTPUT);
  digitalWrite(IO1, HIGH);
  pinMode(IO2, OUTPUT);
  pinMode(O3, INPUT);
  pinMode(O4, INPUT);

  pinMode(analogIn, INPUT_ANALOG);  // Set ADC pin (PA0 as an example)


  pinMode(O4, INPUT_PULLDOWN);  // Set PB13 as input with pull-down resistor

  attachInterrupt(digitalPinToInterrupt(O4), handleInterrupt, RISING);



  sensors.begin();

  tuss4470Write(0x10, 0x1E);  // Set BPF center frequency to 200kHz TODO:reg check why 0x1E and not 0x0F!

  tuss4470Write(0x13, 0x00);

  tuss4470Write(0x16, 0x1F);  // Enable VDRV (not Hi-Z)
  tuss4470Write(0x1A, 0x1F);  // Set burst pulses to 16

  tuss4470Write(0x17, 0x19); // enable threshold detection (Pin 5 and 3 need to be connected to work!)


  // Enable Clocks for ADC1 and GPIOB
  RCC->APB2ENR |= RCC_APB2ENR_ADC1EN;  // Enable ADC1 clock
  RCC->APB2ENR |= RCC_APB2ENR_IOPBEN;  // Enable GPIOB clock

  // Configure PB0 as Analog Input
  GPIOB->CRL &= ~(GPIO_CRL_MODE0 | GPIO_CRL_CNF0);

  // Configure ADC1 (Channel 8)
  ADC1->SQR3 = ANALOG_IN_CHANNEL;  // Select ADC1_IN8
  ADC1->SMPR2 |= ADC_SMPR2_SMP8_1 | ADC_SMPR2_SMP8_2;  // Set 55.5 cycles sample time (fast but stable)

  // Enable ADC
  ADC1->CR2 |= ADC_CR2_ADON;
  delay(1);
  ADC1->CR2 |= ADC_CR2_ADON;  // Required second ADON to start ADC

  Serial1.print("setup done!");

}

void loop() {

  // Check if data is available on the serial port
  if (Serial.available() > 0) {
    String input = Serial.readStringUntil('\n');  // Read input string until newline

    input.trim();  // Remove leading/trailing whitespaces

    // Check if the input starts with "0x" and is a valid hex string
    if (input.startsWith("0x") && input.length() > 2) {
      // Convert the hex string (without "0x") to an integer
      long hexValue = strtol(input.substring(2).c_str(), NULL, 16);

      // Now, execute the tuss4470Write with the new input as the second parameter
      tuss4470Write(0x13, hexValue);
    }
  }



  //int oldMillis = micros();
  tuss4470Write(0x1B, 0x01);
  generateBurst(18);

  for (sampleIndex = 0; sampleIndex < NUM_SAMPLES; sampleIndex++) {
    ADC1->CR2 |= ADC_CR2_ADON;  // Start Conversion
    while (!(ADC1->SR & ADC_SR_EOC));  // Wait for conversion to complete
    analogValues[sampleIndex] = ADC1->DR;  // Read ADC value
    if (sampleIndex == BLINDZONE_SAMPLE_END) detectedDepth = false;
  }

  tuss4470Write(0x1B, 0x00);
  //Serial1.println(micros() - oldMillis);

  if (millis() - lastReadTime >= interval) {
    lastReadTime = millis();
    sensors.requestTemperatures();  // Request temperature conversion
    temperature = sensors.getTempCByIndex(0);  // Get temperature
  }

  Serial1.print("dds"); // depth detect sample
  Serial1.print(depthDetectSample);
  Serial1.print(";tmp"); // depth detect sample
  Serial1.print(temperature);
  Serial1.print(";sp");

  for (int i = 0; i < NUM_SAMPLES; i++) {
    Serial.print(analogValues[i]);
    if (i < NUM_SAMPLES - 1) {
      Serial1.print(", ");
    }
  }
  Serial1.println();

  delay(50);
}

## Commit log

2024-07-02 state update
    [CD4060BMT.step, Mini-B USB Vertical.stp, PCB Terminal Block 2 DEG381-3.5.step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]
2024-12-10 added test hardware for TUSS4470
    [TUSS4470TRTJR.step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]
2024-12-12 fixed fooprint c3 and minor design changes
    [TUSS4470_shield-B_Cu.gbr, TUSS4470_shield-B_Mask.gbr, TUSS4470_shield-B_Paste.gbr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]
2025-01-03 hardware arduino tuss4470 shield added
    [prototype_01.kicad_pcb, prototype_01.kicad_sch]
2025-01-03 added working tuss4470 arduino code
2025-01-20 added more software settings aand current experimentation state (200kHz DIY transducer, python visualizaiton, TUSS4470 integration with improved settings)
2025-01-21 added higher baud and sample example
2025-01-21 added advanced settings for tuss4470 example. now 10x faster sampling on Arduino UNO
2025-01-21 removed old schematic of LUCKY fishfinder
    [CD4060BMT.step, Mini-B USB Vertical.stp, PCB Terminal Block 2 DEG381-3.5.step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]
2025-01-21 removed old prototype
    [prototype_01.kicad_pcb, prototype_01.kicad_sch]
2025-01-21 major cleanup
    [TUSS4470TRTJR.step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]
2025-01-23 Update README.md
    added up to date echograms and transducer assembly image
2025-03-21 added new firmware for STM32F103 all-in-one board and waterfall chart with threshold detect, temperature, settings sender in pyqt
2025-03-27 updated TUSS4470 arduino shiled to new pinout for pin 4,5 -> now 2,3 for interrupt. small design changes and label fixes
    [TUSS4470TRTJR.step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]
2025-03-27 removed old faulty tuss4470 shield
    [TUSS4470TRTJR.step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]
2025-05-21 added binary protocol, many smaller changes, for TUSS4470 shield and all in one transducer
    [TUSS4470_shield-B_Cu.gbr, TUSS4470_shield-B_Mask.gbr, TUSS4470_shield-B_Paste.gbr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]
2025-06-02 added latest version 2 files for production run 2
    [TUSS4470_shield.kicad_pcb, TUSS4470_shield.kicad_sch, TUSS4470_shield.step]
2025-07-03 added latest arduino firmware
2025-07-11 added latest interface image, fixed TCP connection, improved settings menu
    [echo_interface.py]
2025-07-15 added powerline noise example
2025-07-15 Update README.md
    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
2025-07-16 fixed sample size mismatch
    [echo_interface.py]
2025-09-11 Add code for Arduino R4
2025-09-16 updated ordering files
    [bom.csv, positions.csv]
2025-11-26 fix(R4): set pulse counter to 0
    [TUSS4470_arduino_r4.ino]
2025-12-02 fixed (ignored) checksum mismatch issue, changed threshold value to 0x1F, minor cleanup
    [TUSS4470_arduino.ino, echo_interface.py, settings.h]
2025-12-04 fix: checksum mismatch issue
    [PICOW2040_TUSS4470.ino, TUSS4470_arduino.ino, TUSS4470_arduino_r4.ino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]
2025-12-04 fix(R3): checksum error due to ram overload
    [TUSS4470_arduino.ino]
2026-01-02 Update README.md
    fixed image with false GND polarity
2026-01-15 added UART -> UDP relay script
2026-10-05 added version 3 arduino shield (boost converter, voltage monitor, signal improvements)-> way better not ready for community yet.
    [TUSS4470TRTJR.step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]
